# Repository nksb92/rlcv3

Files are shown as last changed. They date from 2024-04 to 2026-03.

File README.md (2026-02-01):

# RLCV3 - RGB LED Controller Version 3

RLCV3 is a comprehensive firmware and hardware project for an embedded LED controller based on the Seeedstudio XIAO ESP32-C3 microcontroller. It is designed to control various LED fixtures including light tubes, panels, and spotlights using DMX512 (wired) and Art-Net (wireless) protocols.

## Features

*   **Multi-Protocol Support**:
    *   **DMX512**: Wired communication via RS485 with termination control.
    *   **Art-Net**: Wireless control over WiFi.
*   **Versatile Hardware Support**: Configurable for different hardware profiles (Addressable Strips, PWM MOSFETs, I2C Panels).
*   **Local User Interface**:
    *   128x32 OLED Display (SSD1306).
    *   Rotary Encoder with Push Button for menu navigation.
*   **Thermal Management**: Integrated PWM fan control with zero-RPM mode support.
*   **Software Architecture**: Hybrid event-driven and polling architecture for responsive UI and high-throughput data processing.

## Hardware Variations

The firmware supports four mutually exclusive hardware profiles defined in `config.h`:

1.  **RGB_IC_TUBE**: For addressable RGB LED strips (e.g., WS2815, WS2811).
2.  **RGB_TUBE**: For non-addressable RGB LED strips controlled via MOSFETs (PWM).
3.  **PANEL**: For configurations involving slave devices controlled via I2C (requires cooling fan).
4.  **SPOT**: For single COB RGB LEDs with MOSFET control and active cooling.

## Getting Started

### Prerequisites

*   **Arduino IDE**: The primary development environment.
*   **ESP32 Board Support**: Install the ESP32 core via Board Manager.

### Dependencies

To ensure stability, the following library versions are recommended (as of Firmware 2.0):

*   **ESP Core**: 3.30.3
*   **Adafruit GFX Library**: 1.12.1
*   **Adafruit NeoPixel**: 1.13.0
*   **Adafruit SSD1306**: 2.5.14
*   **ArtnetWifi**: 1.6.1
*   **EncoderButton**: 1.0.6
*   **FastLED**: 3.9.16
*   **esp_dmx**: 4.1.0 (Note: May require specific fixes for ESP32-C3, see Issue #181)

### Configuration

Before compiling, navigate to `RLC_V3/config.h` and select your hardware profile by uncommenting exactly one of the following lines:

```c
#define RGB_IC_TUBE
// #define RGB_TUBE
// #define PANEL
// #define SPOT
```

You can also toggle debug output in the same file:

```c
// #define DEBUGGING_ENABLED
```

## Repository Structure

*   **RLC_V3/**: Main firmware source code.
*   **LaTeX/**: Comprehensive project documentation, including hardware design, theoretical background, and software architecture details.
*   **Scripts/**: Helper scripts (e.g., Python scripts for bitmap generation).

## Documentation

Detailed documentation regarding the hardware design, PCB fabrication, and theoretical background can be found in the `LaTeX` directory.

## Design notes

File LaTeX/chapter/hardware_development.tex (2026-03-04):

\section{Hardware Development}
\label{sec:hardware_development}

\subsection{Common Hardware Packages and Components}

The controller board integrates several key hardware packages to realize its functionality. For the \ac{DMX} interface, standard \ac{RJ45} connectors are utilized for physical connectivity. The electrical interface is managed by an SN75176 differential bus transceiver \ac{IC}, which is a common choice for \ac{RS485} communication. To ensure compatibility between the 5V levels of the transceiver and the 3.3V logic level of the \ac{MCU}, a voltage divider circuit is implemented for the data lines. \\

Power regulation is achieved using a switching buck converter, a type of \ac{DCDC} converter, to efficiently step down the input voltage to a stable 5V for the system components. The central processing unit selected for this design is the Seeedstudio XIAO ESP32-C3 \ac{MCU}, which provides the necessary computational power, memory, and peripheral interfaces, including \ac{WLAN} connectivity. User input is primarily handled by a rotary encoder, allowing for menu navigation and parameter adjustment. Visual feedback for the \ac{HMI} is provided by an \ac{OLED} display with a resolution of 128x32 pixels, which communicates with the \ac{MCU} via the \ac{I2C} protocol.

\subsection{Hardware Variations for Light Tube}
The project includes different hardware iterations for the tube light fixtures, primarily differing in their \ac{LED} control methodology:

\begin{description}[style=nextline]
	\item[Light Tube V2] This version employs \ac{MOSFET}s to drive the \ac{RGB} \ac{LED}s of the entire tube. Control is achieved using \ac{PWM} signals for each color channel (Red, Green, and Blue), allowing the overall color and intensity of the tube to be adjusted as a single unit.
	\item[Light Tube V3] This iteration advances to addressable \ac{LED} segments. It utilizes a serial communication protocol, similar to that used by the WS2811 \ac{IC}, to set the color of individual \ac{LED} segments within the tube. This enables more complex lighting effects and patterns by controlling different parts of the tube independently.
\end{description}

\subsection{Hardware Variation for Panel}
The Light Panel variant incorporates several distinct design features tailored to its specific application and components. Thermal management for the densely packed \ac{LED}s and associated electronics is addressed by an 80mm cooling fan mounted on the rear of the panel. This fan's speed is regulated via a \ac{PWM} signal from the main controller, allowing for dynamic adjustment of airflow based on thermal load, thereby optimizing cooling performance while minimizing acoustic noise. \\

For distributing lighting information, the panel employs a hierarchical control system. The \ac{MCU} communicates lighting commands to five independent section control units using the \ac{I2C} protocol. These section control units are built around an ATtiny402 \ac{MCU}. Each of these dedicated section controllers is then responsible for driving a bank of 75 WS2815 \ac{RGB} \ac{LED} \ac{IC}s. Within each section, all 75 \ac{LED}s display the same color, as dictated by their respective section controller, allowing for five distinct color zones across the panel. \\

A notable characteristic of this panel variant is its power system. It operates on a 12 Volt input voltage, distinguishing it from other devices in the project that use 24 Volts. This 12V supply is particularly suitable as the WS2815 \ac{LED} \ac{IC}s are designed to be directly powered from a 12V source. This simplifies the power distribution to the \ac{LED}s, potentially reducing the need for additional voltage regulation steps for the \ac{LED} drivers themselves, although the section control units and main \ac{MCU} would still require appropriate voltage levels (e.g., 3.3V or 5V) derived from this main 12V input.

\subsection{Hardware Variation for Spotlight}
This spotlight device incorporates several key design elements. Effective thermal management is achieved through the use of a dedicated aluminum heatsink, which is actively cooled by an attached fan; this is crucial for dissipating the heat generated by the high-power light source. For the 12V fan a separate power rail is used. The fan is controlled via a \ac{PWM} signal depending on the intensity of the light output.\\

The electronics are housed on a custom \ac{PCB}, specifically designed to conform to the physical dimensions and layout requirements of the fixture. The primary light source is a multi-color \ac{RGB} \ac{COB} \ac{LED} chip, which provides a dense array of \ac{LED}s for bright and uniform color output. Each color channel (Red, Green, and Blue) of this \ac{COB} chip is individually controlled via \ac{PWM} signals, allowing for precise color mixing and intensity adjustment. To shape and direct the light output, the fixture is equipped with a lens designed to focus the beam to a 60° angle, providing a defined area of illumination.

\subsection{Schematic Design}
The initial phase of the \ac{PCB} design involves the detailed creation of schematics using specialized \ac{EDA} software. For this project, schematics have been developed using Autodesk Fusion 360, which integrated the capabilities of the formerly separate Autodesk Eagle software, alongside KiCad version 8. A long-term decision has been made to transition future design work predominantly to KiCad 8, leveraging its open-source nature and comprehensive feature set. \\

Within these software environments, the process includes the careful selection and placement of correct component footprints, which accurately represent the physical dimensions and pin configurations of the parts to be used. If standard footprints are unavailable or unsuitable, custom ones are created. Following this, all necessary logical electrical connections between the components are meticulously drawn, defining the complete circuit topology and its intended behavior. \\

A crucial aspect of the design workflow is the reliance on prior experimental validation. The schematics are not merely theoretical constructs but are developed based on the outcomes of thorough testing and experimentation conducted on breadboard prototypes. This practical approach ensures that the fundamental functions of the circuit and the interplay of its components are proven to be working correctly in a tangible, albeit less permanent, setup. By verifying the design's efficacy at the breadboard stage, the risk of errors in the final \ac{PCB} is significantly mitigated, thereby increasing the confidence in ordering and fabricating \ac{PCB}s that will function as intended from the outset.

\subsection{PCB Design and Fabrication}
The design and fabrication of the \ac{PCB}s for this project adhere to several critical considerations to ensure functionality, reliability, and seamless integration within the overall mechanical design. The physical dimensions of each \ac{PCB} are meticulously planned to fit within the specific mechanical parameters and size constraints dictated by the intended enclosure or mounting arrangement. \\

Careful attention is given to the layout of conductive pathways, with adequate track widths employed for both power and signal lines. Power traces are dimensioned to handle the expected current loads without significant voltage drop or excessive heat generation, while signal traces are routed to maintain signal integrity and minimize noise coupling. \\

Components are strategically placed on the board in logical groups, taking into account their functional relationships as well as the placement of input and output connectors to facilitate straightforward wiring and interaction. Furthermore, informative labels and markings are included on the \ac{PCB} silkscreen layer to display crucial information, such as component designators, polarity indicators, or operational notes like the on/off position for a termination resistor switch. To ensure robust mechanical assembly, mounting holes are strategically placed to align with the mechanical design of the enclosure or support structure. \\

All custom \ac{PCB}s utilized throughout this project are fabricated by the external manufacturing service, JLCPCB. This approach allows for access to professional-grade \ac{PCB} production. A specific consideration applies to the \ac{LED} panel variant: due to the high density of surface-mount \ac{LED}s, the WS2815 \ac{LED} components for these panels are assembled onto the \ac{PCB}s directly by JLCPCB as part of their component assembly service. This outsourcing of the \ac{LED} placement significantly saves time for the assembly process for this particular component-dense design. Further details regarding the overall component assembly process for all boards are provided in a subsequent chapter \textit{\ref{sec:component_assembly} \nameref{sec:component_assembly}}.

\subsection{Component Selection}
A comprehensive list of all components used in this project, including their manufacturers and part numbers, can be found in the Bill of Materials in Table \ref{tab:bom}.

\subsection{Component Assembly}\label{sec:component_assembly}
The assembly of the \ac{PCB}s involves distinct stages for \ac{SMD} and \ac{THT} components, employing manual and semi-automated techniques to ensure reliable solder joints and functional boards. \\

\begin{description}[style=nextline]
	\item[\ac{SMD}] The \ac{SMD} assembly process commences with the application of solder paste to the pads on the \ac{PCB}. A stencil, precisely aligned with the \ac{PCB} footprint, is used to ensure accurate deposition of the paste. To achieve consistent solder paste distribution and ensure repeatability across multiple boards, a temporary jig or contraption is constructed. This setup, typically involving securing the stencil with tape and using other \ac{PCB}s as shims, guarantees the correct height and alignment for an even application. Following solder paste application, the individual \ac{SMD} components are meticulously placed onto their designated positions on the \ac{PCB} using a pair of tweezers. Once all components are placed, the entire assembly is subjected to a reflow soldering process using a hot plate. The controlled heating profile of the hot plate melts the solder paste, allowing it to flow and form robust electrical and mechanical connections between the components and the \ac{PCB}. After the board has cooled, a cleaning step is performed using \ac{IPA} and a brush to remove any flux residues or solder debris, ensuring optimal electrical performance and a professional finish.
	
	\item[\ac{THT}] Subsequent to the completion of the \ac{SMD} assembly and reflow process, the \ac{THT} components are manually soldered to the \ac{PCB}. This step is generally performed for all \ac{THT} parts with the notable exception of the \ac{MCU}, which is handled with additional precaution. Before the \ac{MCU} is installed, a critical verification step involves testing the output of the onboard 5V buck \ac{DCDC} converter. The voltage is carefully measured using a multimeter to confirm it is within the correct operational tolerance. Only if this voltage measurement is confirmed to be fine is the \ac{MCU} then soldered onto the board. This sequenced approach, prioritizing the verification of power rails before installing sensitive components like the \ac{MCU}, minimizes the risk of damage due to power supply faults.
\end{description}

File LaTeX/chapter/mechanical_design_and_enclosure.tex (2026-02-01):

\section{Mechanical Design and Enclosure}
\label{sec:mechanical_design}

\subsection{Manufacturing Technologies and Materials}
\label{subsec:manufacturing_tech}
The mechanical construction of the RLCV3 system relies on a combination of additive manufacturing, standardized metal components, and specialized fastening techniques to achieve a robust and professional assembly.

\subsubsection{Additive Manufacturing (3D Printing)}
The fabrication of custom enclosures, structural brackets, and end caps is performed using \ac{FDM}.
A BambuLab X1C printer, equipped with a textured \ac{PEI} build plate, is utilized to ensure consistent adhesion and a high-quality surface finish.\\ 

Two primary thermoplastic filaments are employed based on the functional requirements of the components:
\begin{itemize}
	\item \textbf{BambuLab PLA-Basic}: This material is used for the majority of the structural parts, including the main PCB enclosures, as well as the housing components for the Spotlight and Panel variants \cite{inet:bambulab_pla}.
	It offers a favorable balance of rigidity and dimensional accuracy.
	\item \textbf{BambuLab PLA-CF}: A Carbon Fiber reinforced \ac{PLA} composite is utilized for the tube light end caps \cite{inet:bambulab_placf}.
	The addition of carbon fiber enhances the stiffness of the parts and provides a distinctive matte surface finish, contributing to the aesthetic quality of the visible components.
\end{itemize}

To ensure mechanical integrity, specific print parameters are strictly adhered to.
Components are fabricated using a 0.4 mm nozzle with a layer height of 0.12 mm, allowing for fine detail resolution.
Structural strength is prioritized through the use of increased wall thickness rather than high infill density.
Parts are typically sliced with 3 to 4 wall perimeters and 2 to 3 top and bottom layers.
The infill density is set between 20\% and 30\%, utilizing 3D-honeycomb or cubic patterns to provide isotropic strength distribution.
Components subjected to higher mechanical stress, such as the connector systems detailed in section \ref{subsec:connection_systems}, are designed with significantly thicker walls to withstand operational loads.

\subsubsection{Fastening Technology}
To ensure durability and serviceability, the assembly avoids the use of direct threading into plastic or loose nuts.
Instead, brass threaded inserts (typically M3) are integrated into the 3D-printed components.
These inserts are installed using a heat-set process, where a soldering iron is used to melt the plastic locally, allowing the knurled insert to sink into the part and bond securely upon cooling.
This method provides medium pull-out resistance and torque capability \cite{inet:cnckitchen_inserts}.
Furthermore, it simplifies the assembly process by eliminating the need for a counter-wrench and allows for repeated disassembly without degrading the fastening interface.

\subsubsection{Aluminum Extrusion Profiles}
The core structure of the light tube variants is formed by an extruded aluminum U-profile \cite{inet:alu_profile_amazon}.
This profile serves a dual purpose: it acts as the rigid chassis for the fixture and functions as a passive heatsink for the LED strips \cite{inet:alu6063_properties}.
The selected profile features a width of approximately 27 mm and a height of 12 mm.
Originally supplied in 2-meter lengths, the profiles are cut to 1 meter.
Light diffusion is achieved via a compatible milky-white diffuser cover, which snaps into the profile and adds 13 mm to the total height.
Although specific manufacturer data regarding the thermal resistance and structural modulus of this profile is unavailable, empirical testing has confirmed its suitability for dissipating the thermal load generated by the LEDs in this application.
The precise dimensions provided by the manufacturer, as well as the profile cross-section, can be seen in figure \ref{fig:aluprofileedgy}.

\begin{figure}[H]
	\centering
	
	\caption{Cross-section of the aluminum U-profile used for the tube light structure.}
	\label{fig:aluprofileedgy}
\end{figure}

\subsection{Light Tube Enclosures}
\label{subsec:light_tube_enclosures}
	Holes are drilled through the aluminum profile, and screws are inserted from the inside channel (the surface to which the \ac{LED} strip is adhered).
	These screws engage with the threaded inserts installed in the 3D-printed parts.
	This approach ensures a clean exterior finish with no visible screw heads on the printed parts and provides a secure mechanical connection.
	Typically, each major component is secured with four screws to prevent rotation and ensure structural rigidity.

\subsubsection{Variant V2 (MOSFET)}
\label{subsubsec:light_tube_v2}
In the V2 iteration, the mechanical design integrated the controller housing directly into one of the end caps.
This single-piece assembly served as both the termination for the tube and the enclosure for the \ac{PCB}.
Mechanical mounting for the fixture was provided via a standard tripod screw thread embedded in the housing.
However, this design lacked the modularity required for more advanced mounting scenarios.
Consequently, this mechanical configuration is considered deprecated.
The V2 electronic hardware is compatible with the improved V3 mechanical design, and therefore, no further development is being conducted on the specific V2 enclosure geometry.

\subsubsection{Variant V3 (Addressable)}
\label{subsubsec:light_tube_v3}
The V3 design represents the current standard for the light tube fixtures, featuring a more modular and robust architecture.
The assembly consists of distinct end caps at both the top and bottom of the tube, which incorporate mechanical interfaces for the connector systems.\\

The controller electronics are housed in a dedicated, two-part enclosure mounted along the length of the profile, rather than at the end.
This enclosure comprises a base plate, which is bolted to the aluminum profile and supports the \ac{PCB}, and a removable lid.
The lid protects the electronics while providing necessary apertures for the \ac{OLED} display, input connectors, and the rotary encoder.\\

Electrical connection between the external controller and the internal \ac{LED} strip is achieved by routing three separate cables through drilled holes into the profile's interior.
To facilitate precise assembly, a 3D-printed drill template is available, allowing the user to accurately mark all 14 required holes: 12 for mechanical fastening of the components and 2 for wire feed-throughs.
Inside the profile, a specialized clip is used to secure the data wire.
This clip is designed to be held in place by the adhesive backing of the \ac{LED} strip itself, ensuring the internal wiring remains unobtrusive and does not cast shadows on the diffuser.\\

\subsection{Panel Enclosure}
\label{subsec:panel_enclosure}
The enclosure for the Panel Light variant is constructed around a central structural component, referred to as the main body.
This part serves as the mounting interface for the electronic subsystems, with the \ac{LED} driver \ac{PCB}s positioned on the front face and the main control unit secured to the rear. \\

Electrical connectivity between the rear-mounted controller and the front-facing \ac{LED} modules is established via four wires (carrying power and \ac{I2C} signals), which are routed through a dedicated feed-through channel within the main body.
The lighting array consists of five distinct segments, each managed by its own driver \ac{PCB} mounted on the front.\\

Thermal management is addressed by a cooling fan located at the rear, which is enclosed by a protective lid.
Similarly, the \ac{LED} driver \ac{PCB}s on the front and the main control \ac{PCB} on the back are shielded by their respective covers to ensure safety and prevent accidental contact.\\ 

For positioning and mounting, the assembly features a U-shaped frame.
This frame allows for tilt adjustment and attachment to a standard tripod, secured using an M8 bolt and a wing nut for tool-free adjustment.
Additionally, the design accommodates a diffuser, which can be mounted in conjunction with the U-frame to soften the light output.

\subsection{Spotlight Enclosure}
\label{subsec:spotlight_enclosure}
The mechanical design of the Spotlight variant is centered around a high-performance aluminum heatsink equipped with an active cooling fan, essential for dissipating the heat generated by the high-power \ac{COB} \ac{LED}.\\

The main enclosure body wraps around this heatsink and forms the front face of the fixture.
It features a central aperture designed to accommodate a $60^{\circ}$ lens, which directs the light output.
Internally, a specialized diffusion cube, printed from transparent \ac{PETG} \cite{inet:bambulab_petg}, is positioned between the \ac{LED} and the lens.
This component is critical for blending the distinct red, green, and blue zones of the \ac{COB} \ac{LED} to ensure a uniform color mixture before the light passes through the lens.\\

The control \ac{PCB} is mounted directly to the main body.
A dedicated lid covers the electronics, providing necessary cutouts for peripheral connections and user interface elements.
Similar to the Panel variant, the Spotlight utilizes a U-shaped mounting frame.
This frame facilitates tilt adjustment and tripod mounting, secured via an M8 bolt and a wing nut, allowing for flexible positioning in various lighting setups.

\subsection{Connection Systems}
\label{subsec:connection_systems}
The system features two distinct connection methods designed to address different use cases, ranging from rapid, temporary mounting to robust, structural assembly.

\subsubsection{System \enquote{click \& hope}}
The \enquote{click \& hope} system is a friction-fit mounting solution designed to engage with the external longitudinal grooves of the aluminum profile.
Due to this specific mechanical interface, it is exclusively compatible with the light tube variants.
The primary advantage of this system is the speed of assembly, allowing for the quick attachment of accessories such as tripod mounts.
These mounts typically integrate a threaded insert to interface with standard photography equipment and feature a rosette coupling to enable discrete rotational adjustment. \\

Despite its convenience, the system relies on the clamping force of the printed parts against the profile grooves.
Consequently, it is less structurally secure than bolted connections.
While a spacing bracket for aligning multiple tubes has been prototyped, the ecosystem for this mounting standard is limited.
Due to the superior reliability of the end-cap-based mounting system, further development of this clip-on mechanism is currently not planned.

\subsubsection{System \enquote{screw it!}}
In contrast to the friction-based approach, the \enquote{screw it!} system offers a robust, mechanical interlocking connection.
This system utilizes the structural hardpoints integrated into the end caps of the V3 light tube variants to facilitate the creation of complex, multi-fixture arrays.\\

A comprehensive suite of modular connector components has been developed to support various geometric configurations, including linear couplers, T-pieces, and cross-connectors.
For free-standing applications, specialized feet are utilized.
These feet consist of 3D-printed shells filled with plaster to provide the necessary ballast.
A key maintenance feature of the feet is the detachable mounting adapter; this design allows for the replacement of the mechanical interface in the event of damage without requiring the disposal of the entire weighted base. \\

Assembly is achieved by inserting screws from the rear of the connector components, which engage with the threaded inserts in the tube end caps.
To ensure a seamless appearance and structural rigidity, a clamping mechanism can be applied from the front.
This clamp actively pulls the connected tubes towards the central connector hub, minimizing gaps and preventing rotation.
Figure \ref{fig:crossconnectorclamp} illustrates this assembly from a side perspective to demonstrate the interconnection of parts; for clarity, the end caps are rendered in green, the cross-connector in blue, and the clamping mechanism in red.
Technical drawings detailing the dimensions and tolerances of this interface are provided in appendix~\ref{sec:cad_models} \nameref{sec:cad_models}.

\begin{figure}[H]
	\centering
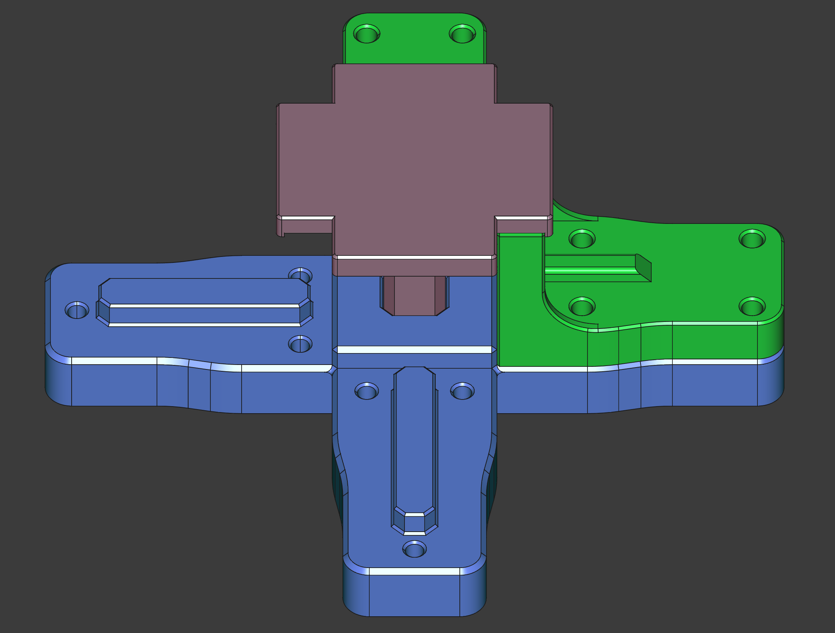
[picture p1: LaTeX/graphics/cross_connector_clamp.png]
	
	\caption{Cross connector with two end caps and clamp mechanism.}
	\label{fig:crossconnectorclamp}
\end{figure}

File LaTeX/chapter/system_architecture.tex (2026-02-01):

\section{System Architecture}
\label{sec:system_architecture}
\subsection{Hardware Core System Block Diagram}
\begin{figure}[H]
	\centering
	
	\caption{Hardware System Architecture}
	\label{fig:hardwarearchitecture}
\end{figure}
The hardware architecture of the developed embedded \ac{LED} controller is segmented into three primary functional blocks: input, processing, and output. This design facilitates modularity and clear separation of concerns within the system. The schematic representation of this architecture can be seen in the provided diagram.

\subsubsection*{Input Block}

The input block is responsible for receiving power, data, and user commands.

\begin{itemize}
	\item \textbf{Power Supply:} The system accepts a flexible \ac{DC} input voltage ranging from 12V to 24V via a dedicated connector. This allows for compatibility with common power supplies found in lighting applications.
	\item \textbf{Programming and Debugging:} A \ac{USB} Type C interface is incorporated for firmware flashing, debugging, and potential serial communication during development.
	\item \textbf{Wired Communication:} An \ac{RS485} interface enables robust, long-distance wired communication, commonly used for protocols like \ac{DMX} in lighting control. A notable feature is an integrated switch to engage or disengage a 120 Ohm termination resistor, crucial for maintaining signal integrity in \ac{RS485} networks.
	\item \textbf{User Interface:} Direct user interaction is managed by a rotary encoder equipped with a push-button function. This allows users to navigate menus displayed on the \ac{HMI} and confirm selections.
	\item \textbf{Wireless Communication:} The controller integrates a 2.4 GHz \ac{WLAN} interface, enabling it to connect to standard wireless networks. This facilitates wireless control primarily through the Artnet protocol, a common standard for transmitting \ac{DMX} data over Ethernet networks.
\end{itemize}

\subsubsection*{Processing Block}

The processing block handles power regulation and executes the core logic of the controller.

\begin{itemize}
	\item \textbf{Power Conversion:} An essential component is the 5V DC-DC converter. This module steps down the incoming 12/24V supply to a regulated 5V. This stable 5V rail powers the sensitive electronic components, including the microcontroller and the display. \\
	For the spotlight a DC-DC converter provides a 12 V power rail. In this case, the input voltage does not match the fan voltage and is therefore needed. 
	\item \textbf{\ac{MCU}:} The central processing unit is the Seeedstudio XIAO ESP32-C3 microcontroller. This \ac{MCU} was chosen for its integrated Wi-Fi capabilities, sufficient processing power for handling communication protocols and control algorithms, and its compact form factor. It executes the firmware that manages inputs, processes control data (e.g., Artnet, \ac{DMX}), and drives the outputs.
\end{itemize}

\subsubsection*{Output Block}

The output block interfaces with the external components that the controller manages.

\begin{itemize}
	\item \textbf{\ac{LED} Control:} The primary function is controlling \ac{LED} hardware. The system is designed to support two main methods: direct serial communication for addressable \ac{LED} strips and \ac{PWM} control for driving different color channels (e.g., \ac{RGB}) of non-addressable \ac{LED}s.
	\item \textbf{Display Interface:} An \ac{I2C} interface is utilized to communicate with the \ac{OLED} display, which serves as the \ac{HMI}. In certain product configurations, such as integrated panel lights, this \ac{I2C} bus may also be used to send control data to other integrated components. An \ac{I2C} level converter is included to shift voltage levels between the 3.3V logic of the \ac{MCU} and the 5V requirement of the other peripherals. The display works with either 3.3V logic or 5V. To only drive the display, the level converter is not needed.
	\item \textbf{Thermal Management:} To ensure reliable operation, the controller incorporates fan control via a standard \ac{PWM} interface, compatible with typical computer fans. This allows the system to regulate its temperature under load.
\end{itemize}

\subsection{Hardware Configuration Options}
While the core architecture remains consistent, different hardware configurations and \ac{PCB}s are available to suit various application requirements:

\begin{itemize}
	\item \textbf{Tube Light V2 (Non-Addressable \ac{LED}s):} This variant utilizes hardware supporting three \ac{PWM} outputs for controlling non-addressable \ac{LED} strips. It omits the fan control output as it's not typically required for this configuration.
	\item \textbf{Tube Light V3 (Addressable \ac{LED}s):} For tube lights using addressable \ac{LED}s, the hardware provides support for a serial data output. Similar to the non-addressable version, fan control is not included.
	\item \textbf{Panel Light:} This configuration uses the same fundamental hardware as the addressable \ac{LED} tube light (serial output capable). However, the \ac{RGB} data for the panel is specifically transmitted via the \ac{I2C} interface instead of the dedicated serial \ac{LED} output. This version includes the hardware connection for fan control.
	\item \textbf{Spot Light:} The spot light employs an individual \ac{PCB} design tailored to its needs. It features three \ac{PWM} outputs for \ac{LED} control and includes the hardware connection for fan control.
	The size of the \ac{PCB} is designed to fit within the casing. The previous \ac{PCB} would not fit.
\end{itemize}

These variations ensure that each product type has an optimized hardware platform based on the core controller design, omitting unnecessary components or adapting interfaces as needed for the specific application.

\subsection{Software Architecture}
\subsubsection{Overview} 
The software architecture utilizes a hybrid execution approach to balance responsiveness with high-throughput data processing. Asynchronous user inputs and low-frequency tasks, such as display updates or button presses, are handled via an event management system. Conversely, high-frequency tasks requiring immediate execution are managed through continuous polling. Additionally, a software timer module is integrated to inject time-based triggers into the event queue.

\subsubsection{Event Management} 
The system implements an event manager utilizing a \ac{FIFO} buffer to store and sequence system events. These events are retrieved and processed sequentially within the main loop via the \textit{process\_event} function. Event definitions and properties are isolated in specific configuration files, facilitating modular adjustments.
Within sourcecode section \ref{pc:event_manager_config} such a configuration can be seen. 

\begin{listing}[H]
	\begin{minted}[autogobble, linenos=true, numberblanklines=true, frame=leftline, framesep=5pt, numbersep=5pt, style=vs, tabsize=2, xleftmargin=10pt, breaklines, fontsize=\small, baselinestretch=1.0, escapeinside=!!]{c}
		const event_cfg_t event_config[] = { 
			// ID Name Priority Queueable {EVT_NONE, "None", EVT_PRIORITY_LOW, false},
			// Input events
			{EVT_ENCODER_CHANGED, "EncoderChanged", EVT_PRIORITY_HIGH, true},
			{EVT_BUTTON_CLICK, "ButtonClick", EVT_PRIORITY_HIGH, false},
			// System events
			{EVT_SAVE_TO_NVM, "SaveToNvm", EVT_PRIORITY_NORMAL, false},
			{EVT_DISPLAY_WAKE, "WakeUpDisplay", EVT_PRIORITY_NORMAL, false},
		};
	\end{minted}
	\caption{Configuration of the event manager system}
	\label{pc:event_manager_config}
\end{listing}

It is possible for the handling of one event to trigger the posting of subsequent events. This capability must be utilized cautiously to prevent the creation of infinite feedback loops where events recursively trigger one another.

\subsubsection{Software Timer Management} 
Software timers are employed to generate events based on time intervals, operating with a time base of 1 ms. The TimerManager checks all active timers for expiry during every iteration of the main loop. Upon expiry, the manager automatically adds the associated event to the FIFO queue. The system supports two operational modes: 

\begin{itemize} 
	\item \textbf{Periodic:} The timer automatically reloads and restarts after expiry. 
	\item \textbf{One Shot:} The timer is disabled immediately after the expiry event is generated.
\end{itemize}
Similar to the configuration of the event manager, the software timers can be configured through a list. 
Each entry represents one timer configuration. 

\subsubsection{Menu Structure}
User interaction with the device primarily occurs through the rotary encoder and its integrated push button, as depicted in the menu structure diagram figure \ref{fig:menustructure}.
\begin{figure}[H]
	\centering
	
	\caption{Structure of the main menu navigation}
	\label{fig:menustructure}
\end{figure}

In the main menu view, turning the rotary encoder allows the user to cycle horizontally through the available function selections (such as \acs{HSV}, \ac{RGB}, \ac{DMX}, Artnet, and Options). The selection does not jump from the last to the first or from the first to the last entry of the menu. 
At both ends an end mark is displayed as user information. \\

Vertical navigation between the main menu level and the corresponding submenu pages is achieved via a long press on the encoder's button. Performing a long press while a main menu item is selected transitions the software into that item's specific submenu, displaying its parameters or options. Conversely, performing another long press while within a submenu returns the user to the main menu selection screen. This hierarchical navigation, visually represented in the provided diagram, allows access to different functionalities and their settings using simple rotary and press actions.

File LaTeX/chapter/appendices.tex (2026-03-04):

\section{Schematic Diagrams}
\begin{figure}[H]
	\centering
	
	\caption{Circuit Diagram Tube V3}
	\label{fig:circuitdrawing}
\end{figure}
\clearpage

\section{Source Code}
The complete source code for the firmware, along with the hardware design files and 3D models, is hosted on GitHub.
The repository can be accessed via the following link: \\
\url{https://github.com/nksb92/rlcv3}
\clearpage

\section{Bill of Materials (BOM)}
\begin{table}[H]
	\centering
	\resizebox{\textwidth}{!}{%
		\begin{tabular}{|l|l|l|l|l|l|l|l|l|l|}
			\hline
			\textbf{Name on PCB} & \textbf{Package} & \textbf{Value} & \textbf{Name} & \textbf{Vender} & \textbf{Part Nbr.} & \textbf{Link} & \textbf{Price One 2025-04-17} & \textbf{Quantity} & \textbf{Total} \\ \hline \hline
			C1, C2, C4, C6, C8 & C1206 & 100n & Capacitor & Mouser & C1206C104K5RAC7867 & \href{https://www.mouser.de/ProductDetail/80-C1206104K5RAC7867}{\textit{View...}} & 0,11305 & 5 & 0,57 € \\ \hline
			C10, C11 & C0805 & 100n & Capacitor & Mouser & 08055C104KAT2A & \href{https://www.mouser.de/ProductDetail/581-08055C104K}{\textit{View...}} & 0,11305 & 2 & 0,23 € \\ \hline
			C12, (C7) & C0805 & 1u & Capacitor & Mouser & 08055C104KAT2A & \href{https://www.mouser.de/ProductDetail/581-08055C104K}{\textit{View...}} & 0,11305 & 1 & 0,11 € \\ \hline
			C3 & C0805 & 10u & Capacitor & Mouser & C0805C106K8PACTU & \href{https://www.mouser.de/ProductDetail/80-C0805C106K8P}{\textit{View...}} & 0,12495 & 1 & 0,12 € \\ \hline
			C9 & C0805 & 4,7u & Capacitor & Mouser & GRM21BZ7YA475KE15K & \href{https://www.mouser.de/ProductDetail/81-GRM21BZ7YA475KE5K}{\textit{View...}} & 0,3094 & 1 & 0,31 € \\ \hline
			D1 & SM71202HTG &  & RS485 Protection & Mouser & SM712-02HTG & \href{https://www.mouser.de/ProductDetail/Littelfuse/SM712-02HTG?qs=aGgfWYEhH7lQgBVBPCUDkw\%3D\%3D}{\textit{View...}} & 0,64498 & 1 & 0,64 € \\ \hline
			D2, D3 & DO-214AC & SK 14 & Diode & Mouser & SK14 & \href{https://www.mouser.de/ProductDetail/637-SK14}{\textit{View...}} & 0,17017 & 2 & 0,34 € \\ \hline
			EN1 & PEC11L-4220F-S0015 &  & Rotary Encoder & Mouser & PEC11L-4220F-S0015 & \href{https://www.mouser.de/ProductDetail/652-PEC11L4220FS0015}{\textit{View...}} & 2,4514 & 1 & 2,45 € \\ \hline
			H1, H2 & 3,2 mm & M3 & Standoff & Mouser & 971080354 & \href{https://www.mouser.de/ProductDetail/710-971080354}{\textit{View...}} & 0,71281 & 2 & 1,43 € \\ \hline
			IC1 & SN75176BDR & RS485 & RS485 Interface & Mouser & SN75176BDR & \href{https://www.mouser.de/ProductDetail/595-SN75176BDR}{\textit{View...}} & 1,07457 & 1 & 1,07 € \\ \hline
			IC2 & SOP65P490X110-8N &  & I2C level shifter & Mouser & TCA9517ADGKR & \href{https://www.mouser.de/ProductDetail/Texas-Instruments/TCA9517ADGKR?qs=\%252BrH4t\%252BeVZ2M4pVnwXR4oNA\%3D\%3D}{\textit{View...}} & 0,94962 & 0 & 0,00 € \\ \hline
			J1 & PJ-044A & DC-Jack & Connector & Mouser & PJ-044A & \href{https://www.mouser.de/ProductDetail/490-PJ-044A}{\textit{View...}} & 0,6902 & 1 & 0,69 € \\ \hline
			J1, J3 & PJ-044A & RJ45 & Connector & Mouser & SS-90000-013 & \href{https://www.mouser.de/ProductDetail/530-SS-90000-013}{\textit{View...}} & 1,7612 & 2 & 3,52 € \\ \hline
			JP2 & 1X04 & OLED & Connector & Amazon & Pin Header & \href{https://www.amazon.de/dp/B09NJMBBLX?ref\_=ppx\_hzsearch\_conn\_dt\_b\_fed\_asin\_title\_3\&th=1}{\textit{View...}} & 0,1402 & 1 & 0,14 € \\ \hline
			JP2 & 1X04 & OLED & Display & Amazon & OLED Display & \href{https://www.amazon.de/dp/B09J7T5SCL?ref\_=ppx\_hzsearch\_conn\_dt\_b\_fed\_asin\_title\_4}{\textit{View...}} & 2,831666667 & 1 & 2,83 € \\ \hline
			L1 & SRN6045 & 15uH & Inductor 15uH & Mouser & NRS6045T150MMGK & \href{https://www.mouser.de/ProductDetail/963-NRS6045T150MMGK}{\textit{View...}} & 0,29393 & 1 & 0,29 € \\ \hline
			R1, R4, R5, R6, R13 & R1206 & 10k & Resistor & Mouser & CRG1206F10K & \href{https://www.mouser.de/ProductDetail/279-CRG1206F10K}{\textit{View...}} & 0,11305 & 5 & 0,57 € \\ \hline
			R2 & R1206 & 120 & Resistor & Mouser & RT0805FRE13120RL & \href{https://www.mouser.de/ProductDetail/603-RT0805FRE13120RL}{\textit{View...}} & 0,11305 & 1 & 0,11 € \\ \hline
			R3 & R1206 & 20k & Resistor & Mouser & RC1206FR-0720KL & \href{https://www.mouser.de/ProductDetail/603-RC1206FR-0720KL}{\textit{View...}} & 0,11305 & 1 & 0,11 € \\ \hline
			R7 & R1206 & 22,1k & Resistor & Mouser & RMCF0805FT22K1 & \href{https://www.mouser.de/ProductDetail/708-RMCF0805FT22K1}{\textit{View...}} & 0,11305 & 1 & 0,11 € \\ \hline
			R8 & R0805 & 115k & Resistor & Mouser & CR0805-FX-1153ELF & \href{https://www.mouser.de/ProductDetail/652-CR0805FX-1153ELF}{\textit{View...}} & 0,11305 & 1 & 0,11 € \\ \hline
			R9, R10, R11, R12 & R0805 & 4k7 & Resistor & Mouser & RK73H2ATTDD4701F & \href{https://www.mouser.de/ProductDetail/660-RK73H2ATTDD4701F}{\textit{View...}} & 0,12019 & 0 & 0,00 € \\ \hline
			S1 & TL3XYO &  & Switch & Mouser & OS102011MA1QN1 & \href{https://www.mouser.de/ProductDetail/611-OS102011MA1QN1}{\textit{View...}} & 0,62237 & 1 & 0,62 € \\ \hline
			U1 & XIAO-ESP32C3 & XIAO-ESP32C3 & Microcontroller & Mouser & 113991054 & \href{https://www.mouser.de/ProductDetail/713-113991054}{\textit{View...}} & 5,6406 & 1 & 5,64 € \\ \hline
			U2 & SOT23-6 &  & Buck converter & Mouser & LMR54406FDBVR & \href{https://www.mouser.de/ProductDetail/595-LMR54406FDBVR}{\textit{View...}} & 1,09718 & 1 & 1,10 € \\ \hline
			&  &  & LED Profile & Amazon & LED Profile & \href{https://www.amazon.de/dp/B07548TMKN?psc=1\&ref=ppx\_yo2ov\_dt\_b\_product\_details}{\textit{View...}} & 11,95 € & 1 & 11,95 € \\ \hline
			&  &  & PCB & JLCPCB &  &  & 0,54 € & 1 & 0,54 € \\ \hline
			&  &  & LED Strip &BTF-Lighting &FCOB SPI RGB IC WS2811 864 & \href{https://www.btf-lighting.com/en-intl/products/fcob-spi-rgb-ic-ws2811-864leds-12v-24v-cob-lights-ra90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}{\textit{View...}} & 5,038 & 1 & 5,04 € \\ \hline
			&  &  & 3D Druck Filament & Bambu Lab & PLA Basic & \href{https://eu.store.bambulab.com/de/products/pla-basic-filament-de?variant=43923829129435}{\textit{View...}} & 1,65 € & 1 & 1,65 € \\ \hline
			&  &  & Threaded Inserts & Amazon & M3S Gewindeeinsatz & \href{https://www.amazon.de/dp/B09ZHSGHXD?ref\_=ppx\_hzsearch\_conn\_dt\_b\_fed\_asin\_title\_5\&th=1}{\textit{View...}} & 0,0899 & 20 & 1,80 € \\ \hline
			&  &  & Screw & Amazon & M3x10 & \href{https://www.amazon.de/gp/product/B01MY4VXCS/ref=ox\_sc\_act\_title\_2?smid=AQ1IBDB6G2RRD\&psc=1}{\textit{View...}} & 0,1099 & 4 & 0,44 € \\ \hline
			&  &  & Screw & Amazon & M3x8 & \href{https://www.amazon.de/gp/product/B08K8FQWCZ/ref=ox\_sc\_act\_image\_1?smid=A1KGD9U4C0ZGWS\&th=1}{\textit{View...}} & 0,119 & 8 & 0,95 € \\ \hline
			&  &  & Screw & Amazon & M3x6 & \href{https://www.amazon.de/gp/product/B08K8F4FL6/ref=ox\_sc\_act\_image\_3?smid=A1KGD9U4C0ZGWS\&th=1}{\textit{View...}} & 0,1046 & 2 & 0,21 € \\ \hline
		\end{tabular}
	}
	\caption[Bill of Materials]{Bill of Materials (Prices from 17.04.2025)}
	\label{tab:bom}
\end{table}
\clearpage

\section{Connection Interfaces}\label{sec:cad_models}
\begin{figure}[H]
	\centering
	
	\caption{Diagram of the connection interface.}
	\label{fig:connectorinterfacetechdrawing}
\end{figure}

\begin{figure}[H]
	\centering
	
	\caption{Diagram of the clamp interface.}
	\label{fig:clampinterfacetechdrawing}
\end{figure}

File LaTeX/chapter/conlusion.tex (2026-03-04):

\section{Conclusion}
\label{sec:conclusion}
A robust firmware implementation for \ac{RGB} \ac{LED} control was developed, incorporating full \ac{DMX}512 and Art-Net protocol integration. The event-driven and timer-based architecture performs reliably and is structured for straightforward extensibility. On the hardware side, the rotary encoder input, \ac{OLED} display, and RJ45/Ethernet interface all operate as specified. The \ac{DC}-\ac{DC} converter supplying the 5 V rail maintains stable operation without significant thermal dissipation. The 3D-printed enclosure meets mechanical requirements, and the screw-terminal interconnect interface functions as intended. \\

The \ac{RS485} \ac{DMX} driver represents the primary area requiring hardware revision. The snap-fit "click \& hope" mechanical connection system proved insufficient in structural rigidity for permanent installations and should be reserved exclusively for temporary fixture assemblies. The spotlight and tube (v3) fixtures are fully operational; the panel light requires further development as outlined in the future work section.

\subsection{Future Work}
\subsubsection{Hardware}
The \ac{RS485} hardware driver requires a redesign to address instability caused by hot-plugging or removing participants on the bus. The revised driver shall integrate bias resistors and optical isolation to decouple the bus from external circuitry. Replacing the current level-shifting approach with a dedicated 3.3 V \ac{RS485} transceiver IC — such as the SP3485 — would eliminate the need for the existing voltage divider. The power supply architecture should be consolidated to a single 3.3 V rail, removing the dual-rail 5 V/3.3 V configuration. Controller migration to a more capable platform, such as the ESP32-S3 or ESP32-C6, warrants evaluation to determine whether the Art-Net transmission latency is bound by processing throughput. For fan control, an optional 12 V rail should be supplied via a dedicated \ac{DC}-\ac{DC} switching converter rather than an \ac{LDO} regulator to improve power conversion efficiency.

\subsubsection{Panel Light}
The light panel should be redesigned as a single-segment, high-power \ac{RGB} module incorporating an integrated heatsink for adequate thermal management. Aluminum heatsink solutions already qualified for comparable panels — such as those used with the Samsung QB288 LM281B — should be considered for adoption. \ac{LED} drive control should be migrated from the current \ac{I2C} slave topology to direct \ac{PWM}-based MOSFET switching, reducing complexity and improving dynamic response. Thermal feedback via dedicated temperature sensors should govern fan speed, replacing the current open-loop, value-driven approach. The control \ac{PCB} rework must also resolve existing \ac{DMX}512 compliance issues.

\subsubsection{Software}
The firmware options menu should expose a function to reset \ac{EEPROM} to factory defaults. A configurable parameter shall allow the user to enable or disable a dedicated dimmer channel for the full tube, including selection of its position within the data frame — either the first or last byte. Color control should be extended to support gradient generation in \ac{HSV} or \ac{RGB} mode, with per-segment individual color assignment and optional interpolation between adjacent segments. Basic generative animations — including rainbow, fire, and candle effects — may be considered for inclusion. The Art-Net implementation requires rework to support more than two universes of data, increasing the addressable segment count for longer \ac{LED} strips. Latency profiling should be conducted to determine whether the issue originates in software or reflects a hardware throughput limitation.

\subsubsection{Hardware Bridge}
A dedicated hardware bridge should be developed, capable of accepting up to four \ac{DMX} input channels and converting to Art-Net output. The device shall incorporate an onboard effects engine supporting configurable fixture profiles for standalone operation. In standalone mode, the output shall be selectable between Art-Net and \ac{DMX}512. The controller platform should be re-evaluated in favor of the STM32 family to meet the processing and peripheral requirements of the bridge functionality.

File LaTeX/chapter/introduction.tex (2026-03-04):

\section{Introduction}
\label{sec:introduction}

\subsection{Motivation}
The effective use of lighting is paramount in creating immersive environments for stage performances, film production, and artistic installations.
The rapid advancement of \ac{LED} technology and embedded systems has democratized access to high-quality lighting tools.
However, a gap often remains between rigid, high-cost professional equipment and fragile, feature-limited hobbyist solutions.
The RLCV3 (\ac{RGB} \ac{LED} Controller Version 3) project was initiated to address this specific niche.
It stems from the need for a highly customizable, robust, and modular lighting ecosystem capable of integrating seamlessly into professional workflows via standard protocols, while remaining accessible and adaptable for custom "light sculpture" configurations.
Building upon the lessons learned from previous iterations, specifically the limitations in mechanical modularity and control resolution encountered in Version 2, this project aims to deliver a professional-grade solution suitable for \ac{DIY} fabrication.

\subsection{Problem Statement and Objectives}
The primary challenge addressed by this work is the development of a unified control architecture capable of driving distinct lighting form factors—specifically linear tubes, flat panels, and spotlights—without requiring disparate hardware designs.
Existing solutions often lack the flexibility to switch between wired \ac{DMX} and wireless Art-Net control within a compact form factor.
Furthermore, mechanical integration in custom builds is frequently overlooked, leading to thermal issues or structural instability.

The specific objectives of this project are:
\begin{itemize}
	\item To design a versatile embedded controller based on the ESP32-C3 \ac{MCU} that supports both wired DMX512 and wireless Art-Net communication.
	\item To develop firmware that adapts to multiple hardware profiles (Addressable \ac{RGB} strips, \ac{PWM} \ac{MOSFET} control, and \ac{I2C}-driven panels) through a centralized configuration mechanism.
	\item To engineer a robust mechanical enclosure system utilizing \ac{FDM} 3D printing and aluminum profiles that facilitates modular interconnection (the "Screw it!" system) and ensures effective thermal management.
	\item To implement a responsive local user interface using an \ac{OLED} display and rotary encoder for standalone configuration.
	\item To validate the system's performance in terms of thermal stability, power reliability, and software responsiveness suitable for live environments.
\end{itemize}

\subsection{Structure of the Article}
The remainder of this document is organized as follows:
\begin{itemize}
	\item \textit{Section \ref{sec:theoretical_background} \nameref{sec:theoretical_background}} provides the theoretical underpinnings, covering embedded systems, \ac{LED} technology, and communication protocols.
	\item \textit{Section \ref{sec:system_architecture} \nameref{sec:system_architecture}} presents the high-level hardware and software design, including the block diagrams and menu structures.
	\item \textit{Section \ref{sec:hardware_development} \nameref{sec:hardware_development}} details the electronic circuit design, \ac{PCB} fabrication, and component selection.
	\item \textit{Section \ref{sec:mechanical_design} \nameref{sec:mechanical_design}} describes the mechanical engineering aspects, focusing on the enclosure design, 3D printing materials, and the modular connection system.
	\item \textit{Section \ref{sec:software_development} \nameref{sec:software_development}} discusses the firmware implementation, including the event-driven architecture, library management, and user interface logic.
	\item \textit{Section \ref{sec:device_assebly} \nameref{sec:device_assebly}} outlines the practical steps for assembling the devices and flashing the firmware.
	\item Finally, \textit{Section \ref{sec:results} \nameref{sec:results}} analyzes the performance of the developed hardware and software, evaluating thermal behavior and overall system functionality.
\end{itemize}

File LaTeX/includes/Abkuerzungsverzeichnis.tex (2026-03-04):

%%%%%%%%%%%%%%%%%%%%%%%%%%%%%%%%%%%%%%%%%%
%%%%%%%% INDEX OF ABBREVITATIONS %%%%%%%%%
%%%%%%%%%%%%%%%%%%%%%%%%%%%%%%%%%%%%%%%%%%
\phantomsection
\addcontentsline{toc}{section}{List of Abbreviations}

\section*{List of Abbreviations}
\begin{multicols}{2}
	\begin{acronym}[1234567890]\itemsep1pt
		\acro{3D}[3D]{Three-Dimensional}
		\acro{API}[API]{Application Programming Interface}
		\acro{AWG}[AWG]{American Wire Gauge}
		\acro{CAD}[CAD]{Computer-Aided Design}
		\acro{COB}[COB]{Chip-on-Board}
		\acro{DC}[DC]{Direct Current}
		\acro{DCDC}[DC-DC]{Direct Current to Direct Current}
		\acro{DIY}[DIY]{Do It Yourself}
		\acro{DMX}[DMX]{Digital Multiplexing}
		\acro{EDA}[EDA]{Electronic Design Automation}
		\acro{EEPROM}[EEPROM]{Electrically Erasable Programmable Read-Only Memory}
		\acro{FDM}[FDM]{Fused Deposition Modeling}
		\acro{FIFO}[FIFO]{First In First Out}
		\acro{GUI}[GUI]{Graphical User Interface}
		\acro{HMI}[HMI]{Human-Machine Interface}
		\acro{HSV}[HSV]{Hue, Saturation, Value}
		\acro{I2C}[I2C]{Inter-Integrated Circuit}
		\acro{IC}[IC]{Integrated Circuit}
		\acro{IDE}[IDE]{Integrated Development Environment}
		\acro{IO}[I/O]{Input/Output}
		\acro{IP}[IP]{Internet Protocol}
		\acro{IPA}[IPA]{Isopropyl Alcohol}
		\acro{LED}[LED]{Light-Emitting Diode}
		\acro{LDO}[LDO]{Low-Dropout Regulator}
		\acro{MCU}[MCU]{Microcontroller Unit}
		\acro{MOSFET}[MOSFET]{Metal-Oxide-Semiconductor Field-Effect Transistor}
		\acro{OLED}[OLED]{Organic Light-Emitting Diode}
		\acro{PCB}[PCB]{Printed Circuit Board}
		\acro{PEI}[PEI]{Polyetherimide}
		\acro{PETG}[PETG]{Polyethylene Terephthalate Glycol}
		\acro{PLA}[PLA]{Polylactic Acid}
		\acro{PNG}[PNG]{Portable Network Graphics}
		\acro{PWM}[PWM]{Pulse Width Modulation}
		\acro{RGB}[RGB]{Red Green Blue}
		\acro{RJ45}[RJ45]{Registered Jack 45}
		\acro{RPM}[RPM]{Revolutions Per Minute}
		\acro{RS485}[RS485]{Recommended Standard 485}
		\acro{SMD}[SMD]{Surface-Mount Device}
		\acro{THT}[THT]{Through-Hole Technology}
		\acro{URL}[URL]{Uniform Resource Locator}
		\acro{USB}[USB]{Universal Serial Bus}
		\acro{VCS}[VCS]{Version Control System}
		\acro{WLAN}[WLAN]{Wireless Local Area Network}
	\end{acronym}
\end{multicols}

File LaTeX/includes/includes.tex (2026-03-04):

%%%%%%%%%%%%%%%%%%%%%%%%%%%%
%%% DOCUMENT
%%%%%%%%%%%%%%%%%%%%%%%%%%%%

\documentclass[12pt,a4paper,captions=tableheading]{article}
% you may add/remove "twoside" above
% or "12pt"

\pdfminorversion=7
\setlength{\headheight}{14.5pt}

%%%%%%%%%%%%%%%%%%%%%%%%%%%%
%%% TIMES-LIKE FONT
%%%%%%%%%%%%%%%%%%%%%%%%%%%%
\usepackage{mathptmx}

%%%%%%%%%%%%%%%%%%%%%%%%%%%%
%%% FONTS ETC.
%%%%%%%%%%%%%%%%%%%%%%%%%%%%

\usepackage[skip=15pt]{caption}
\usepackage[utf8]{inputenc}
\usepackage[T1]{fontenc}
\usepackage[english]{babel}
\usepackage{amsmath}
\usepackage{amsfonts}
\usepackage{amssymb}

%%%%%%%%%%%%%%%%%%%%%%%%%%%%
%%% CODE HIGHLIGHTING
%%%%%%%%%%%%%%%%%%%%%%%%%%%%
\usepackage{fancyvrb}  
\usepackage{minted} 
\usepackage{helvet}

\usepackage{xcolor}
\definecolor{border}{HTML}{ff5500}

\usepackage{tcolorbox}
\usepackage{etoolbox}
% for angular corners, Argument: arc is angular
\BeforeBeginEnvironment{minted}{\begin{tcolorbox}[colback=white, colframe=border, boxrule=0.4mm, arc=15px]}
\AfterEndEnvironment{minted}{\end{tcolorbox}}
\newenvironment{longlisting}{\captionsetup{type=listing}}{}
%\setminted{style=abap}
\setminted{style=arduino}
\usepackage{fancyhdr}
%%%%%%%%%%%%%%%%%%%%%%%%%%%
%%% MISC USEPACKAGES
%%%%%%%%%%%%%%%%%%%%%%%%%%%% 
% font to Times
%\fontfamily{ptm}\selectfont
% font Arial

%\renewcommand{\familydefault}{\sfdefault}
% for figures
\counterwithin{figure}{section}
\usepackage{graphicx}
\graphicspath{ {./graphics/} }
% for the Distances
\usepackage[left=1.50cm, right=1.50cm, top=3.00cm, bottom=2.00cm]{geometry}
% für comment section
\usepackage{verbatim}
% für Zeilenabstand 1,5
\usepackage[onehalfspacing]{setspace}
% for spacing \hlines, default was 3pt,
% but led to a weird overall layout
\usepackage{tabularx}
% for long tables
\usepackage{longtable}
% to use the title and author
%\usepackage{titling}
% the options avoid boxes around the links
\usepackage[colorlinks=false, pdfborder={0 0 0}]{hyperref}
% for bibliography
\usepackage[numbers,square,sort]{natbib}
\bibliographystyle{unsrt}
% for subfigures
\usepackage[caption = false]{subfig}
%\usepackage{subcaption}
%for graphic/ table positioning
\usepackage{float}
%Hurenkind und Schusterjunge unterbinden
\usepackage[subfigure]{tocloft}
\clubpenalty=10000
\widowpenalty=10000
%for no shifting at the beginning of paragraph
\parindent 0pt
%for section in equation number
\numberwithin{equation}{section}
% rotating tables
\usepackage{rotating}
% degree
\usepackage{textcomp}
%line overflow handling
\setlength{\emergencystretch}{10em}
% multirow tables
\usepackage{multirow}
% si units
\usepackage[per-mode = fraction, exponent-product = \cdot, locale = DE]{siunitx}
% variable space
\usepackage{xspace}
%for graphic/ table positioning
\usepackage{float}
%für das Einbinden von Tabellen
\usepackage{booktabs}
%quotation
\usepackage{csquotes}
%abkürzungsverzeichnis
\usepackage[printonlyused]{acronym}
\usepackage{booktabs}
\usepackage{enumitem}
\usepackage{multicol}

\renewcommand{\labelenumii}{\arabic{enumi}.\arabic{enumii}}

%%%%%%%%%%%%%%%%%%%%%%%%%%%%
%%% FORMAT
%%%%%%%%%%%%%%%%%%%%%%%%%%%%

\renewcommand{\cftfigpresnum}{Figure }
\renewcommand{\cfttabpresnum}{Table }
\renewcommand{\listoflistingscaption}{Sourcecode}
\renewcommand{\listingscaption}{Sourcecode}
\renewcommand{\cftfigaftersnum}{:}
\renewcommand{\cfttabaftersnum}{:}

\setlength{\cftfignumwidth}{2.7cm}
\setlength{\cfttabnumwidth}{2.7cm}
\linespread{1.25}
\setlength{\cftfigindent}{0cm}
\setlength{\cfttabindent}{0cm}

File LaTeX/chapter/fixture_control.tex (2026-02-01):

\section{Fixture Control}
\subsection{Daslight 5}

\subsection{ESP32 Artnet}

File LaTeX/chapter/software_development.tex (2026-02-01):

\section{Software Development}
\label{sec:software_development}
\subsection{Development Environment and Tools}
The primary \ac{IDE} employed for the development of the firmware is the Arduino \ac{IDE} \cite{inet:arduino_ide}.
This choice provides a user-friendly \ac{GUI} and a simplified framework for programming embedded systems, managing the underlying complexities of the build process, including the compiler toolchain (e.g., xtensa-esp32-elf-gcc for ESP32-based targets).
Development is conducted using the C++ programming language, tailored with Arduino-specific functions and structures.
The Arduino \ac{IDE} facilitates the installation of necessary board support packages, such as the ESP32 core, through its integrated Board Manager, enabling compilation and code deployment for the target \ac{MCU}.
The specific microcontroller board used in this project is the Seeed Studio XIAO ESP32-C3 \cite{inet:seeed_xiao_esp32c3}.
This board is based on the ESP32-C3 chip, which features a 32-bit RISC-V single-core processor and supports the necessary Wi-Fi connectivity for Art-Net communication. \\

A significant aspect of development within the Arduino ecosystem is the extensive use of libraries.
These include standard Arduino libraries, as well as third-party libraries for specific components like the Adafruit SSD1306 library \cite{inet:ssd1306} for the \ac{OLED} display, and custom-written code modules.
Physical connection to the development boards for programming and data communication is established via a \ac{USB} Type-C interface.
This connection is also utilized for debugging purposes, primarily through the Serial Monitor feature integrated into the Arduino \ac{IDE}, which allows for real-time output of logging messages and variable states from the firmware. \\

To manage code revisions, track changes, and facilitate collaboration, Git is utilized as the \ac{VCS}.
The code repository is hosted on GitHub, allowing for distributed development workflows and maintaining a comprehensive history of the firmware's evolution.

\subsection{Hardware Configuration Management in Software}

The \texttt{config.h} file serves as a centralized compile-time configuration header for the RLCV3 firmware, identified by the \texttt{RLCV3\_FIRMWARE\_VERSION} macro, currently set to "2.0".
Its primary purpose is to adapt the firmware to various hardware targets by defining a specific set of parameters based on a single selected hardware profile.
This is achieved extensively through C preprocessor directives. \\

An important functionality is to toggle debugging information via the serial port.
The option \texttt{DEBUGGING\_ENABLED} toggles between sending information or not.
Different macro definitions are implemented to wrap around the serial print functions.
With this approach, it is not necessary to use a \texttt{\#ifdef} pragma before every serial print call.
The defines for this macro can be seen in source code section \ref{pc:debugging_enabled}.\\
\begin{listing}[H]
	\begin{minted}[autogobble, linenos=true, numberblanklines=true, frame=leftline, framesep=5pt, numbersep=5pt, style=vs, tabsize=2, xleftmargin=10pt, breaklines, fontsize=\small, baselinestretch=1.0, escapeinside=!!]{c}
		// #define DEBUGGING_ENABLED
		#ifdef DEBUGGING_ENABLED
		#define DEBUG_PRINT(...) Serial.print(__VA_ARGS__)
		#define DEBUG_PRINTLN(...) Serial.println(__VA_ARGS__)
		#define DEBUG_PRINTF(...) Serial.printf(__VA_ARGS__)
		#else
		// If disabled, these macros are replaced with nothing
		#define DEBUG_PRINT(...)
		#define DEBUG_PRINTLN(...)
		#define DEBUG_PRINTF(...)
		#endif
	\end{minted}
	\caption{Macro defines for toggling debugging}
	\label{pc:debugging_enabled}
\end{listing}

A core feature is the selection of one out of four mutually exclusive hardware profiles:
\begin{enumerate}
	\item \texttt{RGB\_IC\_TUBE}: For hardware using addressable \ac{RGB} \ac{LED} strips like WS2815 or WS2811.
	\item \texttt{RGB\_TUBE}: For hardware using non-addressable \ac{RGB} \ac{LED} strips controlled by \ac{MOSFET}s via \ac{PWM}.
	\item \texttt{PANEL}: For hardware configurations involving slave devices controlled via \ac{I2C} and requiring a cooling fan.
	\item \texttt{SPOT}: For hardware utilizing a single \ac{COB} \ac{RGB} \ac{LED} with \ac{MOSFET} control and a cooling fan.
\end{enumerate}
A preprocessor check ensures that exactly one of these hardware profiles is uncommented and thus active; otherwise, a compilation error is triggered.\\

Based on the selected hardware profile, a subsequent section defines specific operational parameters.
These parameters include:
\begin{itemize}
	\item \texttt{LED\_OUT\_TYPE}: Specifies the \ac{LED} output control method.
	Possible values are \texttt{LED\_OUT\_RGBIC} for addressable \ac{LED}s, \texttt{LED\_OUT\_MOSFET} for \ac{PWM}-driven \ac{MOSFET} control, or \texttt{LED\_OUT\_I2C} for sending \ac{RGB} and dimmer values to slave devices.
	\item \texttt{NUM\_PIXEL}: Defines the number of individually controllable pixels or segments.
	For non-addressable strips (\texttt{RGB\_TUBE}, \texttt{SPOT}), this is set to 1.
	For addressable strips or panel segments, it is set according to the hardware (e.g., 24 for \texttt{RGB\_IC\_TUBE}, 5 for \texttt{PANEL}).
	The file mandates this value to be between 1 and 170, inclusive.
	\item Pin Definitions: For \texttt{LED\_OUT\_MOSFET} configurations, specific \ac{MCU} pins for Red, Green, and Blue channels (e.g., \texttt{RED\_PIN}, \texttt{GREEN\_PIN}, \texttt{BLUE\_PIN}) are defined.
	\item Fan Control: If a hardware profile requires a fan (indicated by \texttt{FAN\_USAGE}), parameters such as the \ac{PWM} control pin (\texttt{PWM\_PIN}), maximum speed (\texttt{FAN\_MAX\_SPEED}), minimum speed (\texttt{FAN\_MIN\_SPEED}), and zero \ac{RPM} behavior (\texttt{FAN\_ZERO\_RPM}) are defined.
	\texttt{FAN\_ZERO\_RPM} being \texttt{true} allows the fan to turn off below minimum speed, while \texttt{false} clamps it to the minimum speed.
	If \texttt{NO\_FAN} is defined (as in \texttt{RGB\_IC\_TUBE} and \texttt{RGB\_TUBE}), default non-operational fan parameters are set.
\end{itemize}

For instance, if \texttt{SPOT} is selected, \texttt{LED\_OUT\_MOSFET} is defined, along with specific pins for \ac{RGB} control (\texttt{D10}, \texttt{D8}, \texttt{D9}), fan usage is enabled with its control pin set to \texttt{D3}, a speed range from 75 to 255, and \texttt{FAN\_ZERO\_RPM} set to \texttt{true}.
\texttt{NUM\_PIXEL} is set to 1.

The file also incorporates several compile-time checks to validate the configuration:
\begin{itemize}
	\item Verification that \texttt{NUM\_PIXEL} is defined and within the range of 1 to 170.
	\item If \texttt{FAN\_USAGE} is defined, it checks that \texttt{PWM\_PIN}, \texttt{FAN\_MAX\_SPEED}, \texttt{FAN\_MIN\_SPEED}, and \texttt{FAN\_ZERO\_RPM} are all defined.
	\item If \texttt{LED\_OUT\_MOSFET} is defined, it ensures that \texttt{RED\_PIN}, \texttt{GREEN\_PIN}, and \texttt{BLUE\_PIN} are defined.
\end{itemize}
These checks help prevent runtime errors due to incomplete or inconsistent hardware configurations.

In summary, \texttt{config.h} provides a flexible and robust mechanism for managing firmware configurations across different hardware variations from a single codebase, leveraging C preprocessor directives for conditional compilation and validation.

\subsection{Core Application Architecture}
The firmware's logic is driven by a custom-built, cooperative multitasking architecture centered around an event-driven state machine, supplemented by continuous polling for high-frequency tasks.
This hybrid approach ensures both a responsive user interface and efficient handling of real-time data streams like Art-Net.

\subsubsection{Event Handling}
The event system is the backbone of the application and consists of two primary components: the \texttt{event\_manager} and the \texttt{event\_handler}.
\begin{description}[style=nextline]
    \item[\texttt{event\_manager}] This module acts as a centralized \ac{FIFO} queue for all system events.
								   Events can be generated from multiple sources: user interaction (e.g., \texttt{EVT\_ENCODER\_CHANGED} from the rotary encoder), software timers (e.g., \texttt{EVT\_DISPLAY\_SLEEP}), or even from within other event processing routines.
								   The manager ensures that events are stored and processed in the order they are received, with an optional priority system.
    \item[\texttt{event\_handler}] This is the core state machine of the entire application.
								   In the main loop, the \texttt{event\_handler} continuously dequeues events from the \texttt{event\_manager} via its \texttt{process\_event} function.
								   It contains a large switch-case statement that directs program flow based on the current event and the system's state (e.g., the active menu).
								   It is responsible for delegating tasks to the appropriate modules, such as updating the display, saving settings, or changing LED values.
\end{description}

\subsubsection{Menu and State Management}
The user interface's state is managed by a two-tiered state machine system, which provides a clear separation between the main navigation and the detailed settings menu.
\begin{description}[style=nextline]
    \item[\texttt{menu\_structure}] This class manages the top-level navigation state.
									It tracks which main page is currently active (e.g., HSV, RGB, DMX, Art-Net, Settings) and handles the horizontal scrolling between these pages.
									It determines what is shown on the display and how rotary encoder events are interpreted at this top level.
    \item[\texttt{settings\_menu}] When the user enters the "Settings" page, control is handed over to this secondary state machine.
								   The \texttt{settings\_menu} class exclusively manages navigation and value changes within the various sub-options of the settings screen, such as changing the Art-Net universe or DMX address.
								   This specialized handler simplifies the main menu logic.
\end{description}

\subsubsection{Continuous Tasks}
For operations that require constant, high-frequency updates and cannot wait for the event queue, a set of continuous tasks are executed on every iteration of the main \texttt{loop()}.
These tasks, managed in the \texttt{continuous\_tasks.cpp} file, are primarily responsible for handling the incoming stream of Art-Net or DMX data, ensuring that the LED output is updated in real-time without perceptible latency.

\subsection{Software Modules}
The firmware is divided into several distinct modules, each with a specific responsibility.
These modules are largely decoupled and are controlled by the \texttt{event\_handler}, which dispatches events to them.

\begin{description}[style=nextline]
    \item[\texttt{leds}] This module is an abstraction layer for controlling the \ac{LED}s.
	It exposes simple functions to set colors or segments.
	Internally, it handles the specific output protocol based on the hardware configuration in \texttt{config.h} - whether it's driving addressable \ac{LED} strips (like WS2812B), using \ac{PWM} for non-addressable \ac{RGB} \ac{LED}s, or sending data over \ac{I2C}.
    \item[\texttt{dmx}] Manages all DMX512 communication.
	It can act as a DMX receiver to control the LEDs from an external lighting desk.
	The module is responsible for initializing the DMX port and reading the incoming data.
    \item[\texttt{rlc\_artnet}] Implements the Art-Net protocol \cite{inet:artnet_spec}, allowing the device to receive DMX data over a Wi-Fi network.
	It handles the network connection, subscribing to the correct Art-Net universe, and parsing the incoming packets.
    \item[\texttt{nvm}] The Non-Volatile Memory module is responsible for persisting settings across reboots.
	It provides functions to save and load all user-configurable parameters (e.g., HSV values, DMX address, Art-Net settings) to and from the ESP32's flash memory.
    \item[\texttt{fan\_control}] A simple module to manage the speed of the cooling fan via \ac{PWM}, based on the settings defined in \texttt{config.h}.
    \item[\texttt{segments}] This module implements the logic for dividing an \ac{LED} strip into multiple virtual segments.
	It allows the user to control different parts of a single strip as if they were independent fixtures.
    \item[\texttt{c\_hsv} \texttt{and} \texttt{c\_rgb}] These are data-centric classes that manage the state for the HSV and RGB control modes, respectively.
	They hold the current color values and handle the logic for how user inputs modify these values.
\end{description}

\subsection{User Interface Implementation}
\subsubsection{Library for the OLED Display}
For interfacing with and controlling the \ac{OLED} display, the project leverages the well-established Adafruit SSD1306 library \cite{inet:ssd1306}.
This library is a popular choice within the maker and embedded development communities due to its robustness, comprehensive feature set, and broad compatibility, particularly with Arduino-based environments and \ac{MCU}s like the ESP32-C3. \\

The Adafruit SSD1306 library significantly simplifies the development process by abstracting the low-level I2C communication protocol required to interact with the SSD1306 display controller, which is common in monochrome \ac{OLED} modules with resolutions such as 128x32.
It provides a convenient \ac{API} for tasks essential to updating the display, including initializing the screen, clearing the display area, drawing pixels, rendering text in various fonts and sizes, and displaying basic geometric shapes.
By utilizing this library, developers can efficiently implement the necessary visual feedback for the human-machine interface, such as displaying status information, menu options, or parameter values, without needing to delve into the intricate details of the display's command set.
This allows for a quicker and more focused development of the user interface aspects of the embedded system.

\subsubsection{Creating Bitmaps and Aligning Text}
The creation of graphical assets for the \ac{OLED} display, primarily static bitmaps for icons or user interface elements, and the alignment of both these bitmaps and dynamic text are performed through a multi-stage process involving graphic design tools and code integration. \\

The initial design of graphical elements is carried out using Photopea, a web-based image editing tool that serves as an alternative to Adobe Photoshop \cite{inet:photopea}.
Within Photopea, new documents are created with dimensions matching the native resolution of the target \ac{OLED} display (e.g., 128x32 pixels).
Black and white images are then drawn, typically using the pencil tool to create sharp, pixel-perfect shapes suitable for monochrome displays.
Display content is often broken down into logical sections or screens, such as individual main menu items or status icons.
These distinct graphical elements are typically organized on separate layers.
For efficient export, layers intended for conversion can be marked with a specific suffix (e.g., \texttt{-e-}), enabling bulk export as individual \ac{PNG} image files. \\

Once the \ac{PNG} images are prepared, they are converted into C-style byte arrays using the online utility \texttt{image2cpp} \cite{inet:image2cpp}.
Specific settings are applied during this conversion to ensure compatibility with the embedded system and display library: the background color is set to black, with other general settings often left at their default values.
The code output format is selected as \textit{Arduino Code}.
Crucially, the draw mode is configured to \texttt{horizontal - 1 bit per pixel}, which is optimal for monochrome displays where pixel data is packed efficiently.
Additionally, the option to swap bits within a byte is disabled.
The resulting bitmap arrays are then collated and included in a dedicated header file, named \texttt{bitmaps.h}, within the firmware project.
The methods for drawing these bitmaps onto the display are detailed in a subsequent chapter. \\

For dynamic textual information, such as \ac{RGB} values that change during runtime, rendering is handled directly by calling functions from the display \ac{API}.
This allows for text to be updated on-the-fly.
The process of positioning text elements accurately on the display is often iterative.
An initial visual layout is designed in Photopea to get a preliminary feel for placement.
However, final adjustments to coordinates and alignment are typically made within the firmware code, recompiling and testing until the elements fit precisely as intended on the physical screen.
The positions of the bitmaps can be read directly within Photopea.

\subsubsection{Handling Text and Drawing Bitmaps}
Bitmaps are drawn on the display via the \textit{drawBitmap} method.
This method needs 6 inputs.
First, the x- and y-positions as the starting point.
Then the address of the Bitmap itself.
Also, the width and height need to be defined and passed.
Finally, the color of the display needs to be set. \\

To simplify the call of this method, some helper constructs are defined.
First, two enumerations are defined for the index of the width and height as well as the x- and y-coordinates.
The number of items contained in one array for the information also needs to be defined.
A two-dimensional array for the actual x- and y-coordinates and width and height makes it easy to change values if needed.
All helper functions as well as the bitmap defines can be seen in sourcecode section \ref{pc:helper_enums}.
In this example the code for the main menu items is shown.
To keep the example short, only the first three elements are described.
More details can be seen in the actual sourcecode header file \textit{bitmaps.h}.
\begin{listing}[H]
	\begin{minted}[autogobble, linenos=true, numberblanklines=true, frame=leftline, framesep=5pt, numbersep=5pt, style=vs, tabsize=2, xleftmargin=10pt, breaklines, fontsize=\small, baselinestretch=1.0, escapeinside=!!]{c}
		// defintion of the bitmaps
		const unsigned char BITMAP_LEFT_END_MENU[] PROGMEM = { ... }
		const unsigned char BITMAP_ARTNET_REC_MENU[] PROGMEM = { ... }	
		const unsigned char BITMAP_DMX_MENU[] PROGMEM = { ... }
		// enumeration for addressing in array
		enum {
			LEFT_END_MENU,
			ARTNET_REC_MENU,
			DMX_MENU,
		};
		// enumeration for width and height
		enum {
			WIDTH,
			HEIGHT
		};
		// enumeration for x- and y-alignment
		enum {
			x,
			y
		};
		// define number of bitmaps for array
		#define BITMAP_MAIN_MENU_LEN 3
		// real width and height values
		int W_H_MATRIX_MAIN_MENU[BITMAP_MAIN_MENU_LEN][2] = {
			{ 12, 21 }, // Left end menu
			{ 23, 19 }, // artnet_rec menu
			{ 35, 12 }, // DMX menu
		};
		// real x- and y- coordinates
		int X_Y_MATRIX_MAIN_MENU[BITMAP_MAIN_MENU_LEN][2] = {
			{ 58, 2 },	// Left end menu
			{ 53, 3 },	// artnet_rec menu
			{ 47, 6 },	// DMX menu
		};
		// bitmaps as a array 
		const unsigned char *BITMAP_MAIN_MENU_ARRAY[BITMAP_MAIN_MENU_LEN] = {
			BITMAP_LEFT_END_MENU,
			BITMAP_ARTNET_REC_MENU,
			BITMAP_DMX_MENU,
		};
	\end{minted}
\caption{Helper constructs for drawing bitmaps}
\label{pc:helper_enums}
\end{listing}
These defines and enumerations don't do anything on their own.
In order to display a bitmap on the screen, the information needs to be passed to the \textit{drawBitmap} method.

\subsubsection{Main Menu Item Selection}
Within the main menu, there are always three submenu page options shown.
The first and last ones indicate the start and end of the selection.
These items are not selectable, as they are only indicators.
Figure \ref{fig:menuitemselection} shows the abstract build of the menu structure.
\begin{figure}[H]
	\centering
	
	\caption{Arrangement of the Main Menu Items}
	\label{fig:menuitemselection}
\end{figure}
The selection frame always stays in the same place.
If the user switches the currently selected menu item, the displayed items will be replaced.
Also the menu navigation indicator on the bottom switches to the next selection.
More on this topic in chapter \ref{sec:menu_navigation_indicator} \nameref{sec:menu_navigation_indicator}.
Within the figure the indicator shows the selection of the first menu item.
Switching to the second menu item will shift all previously shown menu items by one to the left.
Therefore, the left menu item will be 1, the middle 2, and the right 3. \\

Scrolling over the edge of the menu is not possible.
If the user reaches the end of the menu and continues switching, nothing will happen.
This means, the user can only switch to the previous item in this instance.
The same occurs with the first item, except the direction changes.

\subsubsection{Menu Navigation Indicator}\label{sec:menu_navigation_indicator}

\begin{figure}[H]
	\centering
	
	\caption{Position indicator for Menu navigation}
	\label{fig:menunavigationindicator}
\end{figure}
Counting the used radii and gaps for each number $n$ results in the list below.
From there, a generalized equation can be formulated.
\begin{align*}
	n = 3  \quad 1.5 \text{ gaps}  \quad 3 \cdot r \\
	n = 4  \quad 2.0 \text{ gaps}  \quad 4 \cdot r \\
	n = 5  \quad 2.5 \text{ gaps}  \quad 5 \cdot r 
\end{align*}
With this listing of possible numbers $n$ one can see, the summed distance on one side of the center of the display is always $n \cdot r$.
The distance with the gaps behaves similarly.
Here is the total distance on one side of the center line $\frac{n}{2} \cdot d_{gap}$.
The following equation to calculate the start x-position can thus be generalized with the radius $r$, the distance of the gap $d_{gap}$, the number of circles to be drawn $n$, and the center display position $x_{center} = 128 / 2$.

\begin{align*}
	 x_{start} = x_{center} - \left( \left(n \cdot r\right) + \left(\frac{n}{2} \cdot d_{gap}\right)\right)
\end{align*}
The start position can therefore be calculated.
From there, a for loop generates the empty circles.
If the index of the current menu item selection is reached, the circle is completely filled.
This is done to symbolize the current position in the menu.
The following are some examples with different numbers of circles.
\begin{align*}
	n & = 3 \quad r = 2 \quad d_{gap} = 5\\
	x_{start_3} &= 64 - \left(\left(3 \cdot 2 \right) + \left(\frac{3}{2} \cdot 5 \right) + 0 \right) = 50.5 \approx 50 \\
	n & = 4 \quad r = 2 \quad d_{gap} = 5\\
	x_{start_4} &= 46 \\
	n & = 5 \quad r = 2 \quad d_{gap} = 5\\
	x_{start_5} &= 41,5 \approx 41
\end{align*}
During testing, it was observed that a correction of one pixel shift to the right improves the result.
This was observed with $n=5$ circles.
For different numbers this might not be needed.
With the correction, the equation \ref{eq:final_calc_dots} can be used in the source code.
\begin{align}\label{eq:final_calc_dots}
	x_{start} = x_{center} - \left( \left(n \cdot r\right) + \left(\frac{n}{2} \cdot d_{gap}\right)\right) + 1
\end{align}

\subsection{Library Version Management}
To ensure stability and prevent compatibility issues that could break the firmware's functionality, it is crucial to use specific versions of the external libraries upon which the project depends.
The firmware has been developed and tested with the following library versions, and adherence to these versions is recommended for compilation and deployment:

\begin{multicols*}{2}	
	\begin{description}[style=nextline]
		\item[ESP Core:] Version 3.30.3
		\item[Adafruit GFX Library:] Version 1.12.1 \cite{inet:adafruit_gfx}
		\item[Adafruit NeoPixel:] Version 1.13.0 \cite{inet:adafruit_neopixel}
		\item[Adafruit SSD1306:] Version 2.5.14 \cite{inet:ssd1306}
		\item[ArtnetWifi:] Version 1.6.1 \cite{inet:artnetwifi}
		\item[EncoderButton:] Version 1.0.6 \cite{inet:encoderbutton}
		\item[FastLED:] Version 3.9.16 \cite{inet:fastled}
		\item[esp\_dmx:] Version 4.1.0 \cite{inet:esp_dmx}. It is important to note that this version may require a specific fix as detailed in the following GitHub issue discussion: \url{https://github.com/someweisguy/esp_dmx/issues/181#issuecomment-2619261884}.
	\end{description}
\end{multicols*}

Using versions different from those listed above may lead to unexpected behavior or compilation errors due to changes in library \ac{API}s or internal functionality.
It is advised to manage these library versions carefully within the development environment.

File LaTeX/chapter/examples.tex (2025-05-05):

\section{Assembly and Integration}
\label{sec:assembly_integration_hw}
\begin{itemize}
	\item Describe the process of assembling the electronic components into the designed enclosures for each product variation.
	\item Mention any challenges or specific steps involved in the mechanical integration.
\end{itemize}

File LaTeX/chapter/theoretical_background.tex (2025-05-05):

\section{Theoretical Background}
\label{sec:theoretical_background}
\subsection{Embedded Systems}
An embedded system is fundamentally a computer system designed for a specific, dedicated function within a larger mechanical or electrical system. It comprises a combination of hardware, typically centered around a processor or \ac{MCU}, memory for storing software and data, and peripheral \ac{IO} devices for interacting with the external environment or the larger system it controls. Unlike general-purpose computers, embedded systems are often constrained by factors such as cost, size, power consumption, and real-time performance requirements, and their software, known as firmware, is specifically tailored to their dedicated task. The \ac{LED} controller developed in this work is an example of such an embedded system.

\subsection{RGB LEDs and Control Methods}
\ac{RGB} \ac{LED}s are semiconductor light sources that combine three individual \ac{LED} elements: red, green, and blue within a single package. By varying the intensity of each primary color, a wide spectrum of colors, including white, can be produced through additive color mixing. Controlling these \ac{LED}s typically involves one of two primary methods relevant to this project. The first method uses \ac{PWM} signals applied independently to each color channel of non-addressable \ac{LED}s, allowing for intensity control of the entire strip or fixture as a single unit. The second method employs addressable \ac{LED}s, where each \ac{LED} (or a small group) incorporates an \ac{IC}. These \ac{IC}s allow the \ac{LED}s to be connected in series and controlled individually via a serial data protocol, enabling complex effects and patterns across the length of an \ac{LED} strip or within a fixture. The choice of control method depends on the specific application requirements, balancing factors like cost, complexity, and the desired level of control granularity.

\subsection{Communication Protocols}
The embedded \ac{LED} controller supports industry-standard communication protocols for receiving lighting control data, enabling integration into various professional and hobbyist setups. Wired communication is primarily handled via the \ac{DMX} protocol, technically known as DMX512. \ac{DMX} is a unidirectional, serial digital protocol transmitted over an \ac{RS485} physical layer, designed for controlling stage lighting and effects. It allows for the addressing and control of up to 512 individual channels within a single "universe," typically corresponding to parameters like intensity or color values for different fixtures. The controller implements \ac{DMX} reception capabilities, allowing it to act as a DMX-controllable device.\\

For network-based control, particularly over wireless networks, the controller utilizes the Art-Net protocol. Art-Net is designed to transmit \ac{DMX} data packets over \ac{IP} networks, leveraging standard networking infrastructure like Ethernet or \ac{WLAN}. This allows for significantly larger systems spanning multiple \ac{DMX} universes and facilitates control from software or consoles connected to the same network. The controller's integrated \ac{WLAN} interface enables it to receive Art-Net commands wirelessly, translating them into the appropriate \ac{LED} output signals. The support for both \ac{DMX} and Art-Net provides flexibility in how the controller is integrated and controlled within a lighting system.

\subsection{User Interface Components}
The primary components facilitating user interaction with the embedded \ac{LED} controller constitute the device's \ac{HMI}. These components allow the user to configure settings, select operating modes, and view status information directly on the device.\\

The main input mechanism is a rotary encoder combined with an integrated push button. This single component serves multiple roles: rotation is used for navigating through menu options or adjusting parameter values, a short press typically confirms a selection or cycles through options within a submenu, and a long press is used to switch between the main menu and submenu levels. This provides a compact and intuitive method for controlling the device's functions without requiring numerous buttons. \\

Visual feedback is provided by a monochrome \ac{OLED} display. This display renders the menu structure, shows current parameter values (such as \ac{HSV} or \ac{RGB} levels, \ac{DMX} addresses, or Art-Net settings), and indicates system status, potentially including connectivity icons or confirmation messages like "Saved". The combination of the rotary encoder input and the \ac{OLED} display output forms the complete local user interface for the controller.

\subsection{Power Supply}
The embedded controller is designed to operate from a flexible main power source, accepting a \ac{DC} input voltage ranging from 12 to 24 Volts via a dedicated connector. Internally, an integrated \ac{DCDC} voltage converter steps this input down to a regulated 5 Volts. This stable 5 Volt supply rail powers the core processing components, including the \ac{MCU} and the \ac{OLED} display. Additionally, the \ac{USB} Type C interface, primarily intended for programming and debugging, can also supply power to the board, typically at 5 Volts, although the main operational power is expected from the 12-24 Volt input.

\subsection{Additive Manufacturing (3D Printing)}\label{subsec:theoretical_3d_printing}
Additive manufacturing, commonly known as \ac{3D} printing, encompasses a set of processes used to create \ac{3D} objects by adding material layer by layer. This approach contrasts fundamentally with traditional subtractive manufacturing methods, which involve removing material from a larger block (e.g., milling or turning). \ac{3D} printing typically starts with a digital model, often created using \ac{CAD} software, which is then sliced into thin cross-sections. The printer deposits, fuses, or solidifies material (such as plastics, resins, metals, or composites) according to these cross-sections, gradually building up the final object. This technology is particularly advantageous for rapid prototyping, creating complex geometries, producing customized parts, and enabling low-volume production runs, such as potentially fabricating custom enclosures or mounting hardware for embedded systems like the one described in this work.

\subsection{Aluminum Extrusion Profiles}\label{subsec:theoretical_aluminum_profiles}
Aluminum extrusion profiles are commonly utilized in mechanical design and construction due to their advantageous properties, including a high strength-to-weight ratio, corrosion resistance, and excellent thermal conductivity. The extrusion process allows for the creation of complex cross-sectional shapes with integrated features like channels, slots, and mounting points. These features make aluminum profiles highly suitable for creating modular and customizable enclosures and structures. In the context of lighting applications, particularly for linear fixtures like the tube light variants developed in this project, these profiles serve multiple purposes. They provide a robust yet lightweight housing, act as an effective heat sink for dissipating thermal energy generated by the \ac{LED}s and electronics, and often include channels designed to hold the \ac{LED} strips, diffusers, and associated \ac{PCB}s securely in place, contributing to a clean and integrated final design.

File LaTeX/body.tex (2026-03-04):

% Preheader
\include{./includes/includes}
% Document

\begin{document}
	
	% Add title without page numbering or any other format
	\pagenumbering{Roman}
	\pagestyle{empty}
	\include{./includes/deckblatt}

	% Display page numbering
	\pagestyle{plain}

	% Table of contents
	\phantomsection
	\addcontentsline{toc}{section}{Contents}
	\tableofcontents
	\newpage
	
	\renewcommand{\arraystretch}{1.5}
	
	% abbreviations
	\include{./includes/Abkuerzungsverzeichnis}
	\newpage
	
	\renewcommand{\arraystretch}{1.25}
	% list of figures
	\phantomsection
	\addcontentsline{toc}{section}{\listfigurename}
	\listoffigures
	\newpage

	% list of tables
	\phantomsection
	\addcontentsline{toc}{section}{\listtablename}
	\listoftables
	
	\newpage
	
	% list of Programmcode
	\phantomsection
	\addcontentsline{toc}{section}{Source Code}
%	\lstlistoflistings	
	\listoflistings
	\newpage
	
	% Include the abstract
	%\phantomsection
	%\input{./chapter/abstract}
	%\newpage
	
	% nomenklatur
	%\input{./chapter/nomenklatur}
	%\newpage

	% change page and chaper numbering
	\pagenumbering{arabic}
	\setcounter{section}{0}

	%%%%%%%%%%%%%%%%%%%%%%%%%%%%%%%%%%%%%%%%%%%%%%%
	%%%%%%%%%%  MAIN PART
	%%%%%%%%%%%%%%%%%%%%%%%%%%%%%%%%%%%%%%%%%%%%%%%
	\pagestyle{fancy}
	\fancyhf{} % Clear all header and footer fields
	\fancyhead[C]{\nouppercase{\leftmark}} % Place the current section title on the left side of the header
	\fancyfoot[C]{\thepage} % Place the page number on the right side of the footer
	\renewcommand{\headrulewidth}{0pt} % Optional: Remove the line above the header
	\renewcommand{\footrulewidth}{0pt} % Optional: Remove the line above the footer
	% ADD YOUR CHAPTER HERE
	\input{./chapter/introduction}
	\newpage
	\input{./chapter/theoretical_background}
	\newpage
	\input{./chapter/system_architecture}
	\newpage
	\input{./chapter/hardware_development}
	\newpage
	\input{./chapter/mechanical_design_and_enclosure}
	\newpage
	\input{./chapter/software_development}
	\newpage
	\input{./chapter/assembly_and_integration}
	\newpage
	\input{./chapter/results}
	\newpage
	\input{./chapter/conlusion}
	\newpage
	\appendix
	\input{./chapter/appendices}
	\newpage
	
	%\input{./chapter/Problemstellung}
	%\newpage
	
	%%%%%%%%%%%%%%%%%%%%%%%%%%%%%%%%%%%%%%%%%%%%%%%
	%%%%%%%%%%  Literature and Appendix
	%%%%%%%%%%%%%%%%%%%%%%%%%%%%%%%%%%%%%%%%%%%%%%%
%	\fancyhf{} % Clear all header and footer fields
	% switch page numberin to roman
	\pagenumbering{Roman}

	% set counter for page numbering.
	% !!!!!!!!!!!!!!!!!!!!!!!!!!!!!!!!!!!!!!!!!!!!!!
	% !!!!!!!!!!!!!!!!!!!!!!!!!!!!!!!!!!!!!!!!!!!!!!
	% Has to be done manually !!!!!!!!!!!!!!!!!!!!!!
	\setcounter{page}{9}

	% Literature
	\phantomsection
	\addcontentsline{toc}{section}{References}
	\bibliography{./includes/literatur}
	\newpage

	% Appendix
	%\appendix

	% Pack den Anhang hier rein
	%\include{./chapter/Anhang}

\end{document}

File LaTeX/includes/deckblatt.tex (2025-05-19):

%% Deckblatt
%\thispagestyle{TitelSeite}
\thispagestyle{empty}
\begin{verbatim}

\end{verbatim}

\begin{center}
\large{Development Notes }

\end{center}

\begin{verbatim}

\end{verbatim}
\begin{center}
	\makebox[\linewidth]{\rule{\linewidth}{0.4pt}}
\end{center}
\begin{verbatim}
	
\end{verbatim}
\begin{center}
	\textbf{\huge RLCV3} 
\end{center}
\begin{verbatim}
	
\end{verbatim}

\begin{center}
	\large Design and Development of an Embedded System Utilizing Dedicated Hard- and Software Subsystems for RGB LED Fixture Control
\end{center}
\begin{verbatim}
	
\end{verbatim}
\begin{center}
	\makebox[\linewidth]{\rule{\linewidth}{0.4pt}}
\end{center}

\begin{verbatim}

\end{verbatim}

\begin{center}
	by Niko Kassubek
\end{center}
%% Ende des Deckblatts

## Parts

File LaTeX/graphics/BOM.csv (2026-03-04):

Name on PCB | Package | Value | Name | Vender | Part Nbr. | Link | Price One 2025-04-17 | Quantity | Total | n | Quantity n | Price for | Available | Need to buy
C1, C2, C4, C6, C8 | C1206 | 100n | Capacitor | Mouser | C1206C104K5RAC7867 | https://www.mouser.de/ProductDetail/80-C1206104K5RAC7867 | 0,11305 | 5 | 0,57 € | 26 | 130 | 14,70 € |  | 130
C10, C11 | C0805 | 100n | Capacitor | Mouser | 08055C104KAT2A | https://www.mouser.de/ProductDetail/581-08055C104K | 0,11305 | 2 | 0,23 € | 26 | 52 | 5,88 € |  | 52
C12, (C7) | C0805 | 1u | Capacitor | Mouser | 08055C104KAT2A | https://www.mouser.de/ProductDetail/581-08055C104K | 0,11305 | 1 | 0,11 € | 26 | 26 | 2,94 € |  | 26
C3 | C0805 | 10u | Capacitor | Mouser | C0805C106K8PACTU | https://www.mouser.de/ProductDetail/80-C0805C106K8P | 0,12495 | 1 | 0,12 € | 26 | 26 | 3,25 € |  | 26
C9 | C0805 | 4,7u | Capacitor | Mouser | GRM21BZ7YA475KE15K | https://www.mouser.de/ProductDetail/81-GRM21BZ7YA475KE5K | 0,3094 | 1 | 0,31 € | 26 | 26 | 8,04 € |  | 26
D1 | SM71202HTG |  | RS485 Protection | Mouser | SM712-02HTG | https://www.mouser.de/ProductDetail/Littelfuse/SM712-02HTG?qs=aGgfWYEhH7lQgBVBPCUDkw%3D%3D | 0,64498 | 1 | 0,64 € | 26 | 26 | 16,77 € |  | 26
D2, D3 | DO-214AC | SK 14 | Diode | Mouser | SK14 | https://www.mouser.de/ProductDetail/637-SK14 | 0,17017 | 2 | 0,34 € | 26 | 52 | 8,85 € |  | 52
EN1 | PEC11L-4220F-S0015 |  | Rotary Encoder | Mouser | PEC11L-4220F-S0015 | https://www.mouser.de/ProductDetail/652-PEC11L4220FS0015 | 2,4514 | 1 | 2,45 € | 26 | 26 | 63,74 € |  | 26
H1, H2 | 3,2 mm | M3 | Spacer | Mouser | 971080354 | https://www.mouser.de/ProductDetail/710-971080354 | 0,71281 | 2 | 1,43 € | 26 | 52 | 37,07 € |  | 52
IC1 | SN75176BDR | RS485 | RS485 Interface | Mouser | SN75176BDR | https://www.mouser.de/ProductDetail/595-SN75176BDR | 1,07457 | 1 | 1,07 € | 26 | 26 | 27,94 € |  | 26
IC2 | SOP65P490X110-8N |  | I2C level shifter | Mouser | TCA9517ADGKR | https://www.mouser.de/ProductDetail/Texas-Instruments/TCA9517ADGKR?qs=%252BrH4t%252BeVZ2M4pVnwXR4oNA%3D%3D | 0,94962 | 0 | 0,00 € | 26 | 0 | 0,00 € |  | 0
J1 | PJ-044A | DC-Jack | Connector | Mouser | PJ-044A | https://www.mouser.de/ProductDetail/490-PJ-044A | 0,6902 | 1 | 0,69 € | 26 | 26 | 17,95 € |  | 26
J1, J3 | PJ-044A | RJ45 | Connector | Mouser | SS-90000-013 | https://www.mouser.de/ProductDetail/530-SS-90000-013 | 1,7612 | 2 | 3,52 € | 26 | 52 | 91,58 € |  | 52
JP2 | 1X04 | OLED | Connector | Amazon | Pin Header | https://www.amazon.de/dp/B09NJMBBLX?ref_=ppx_hzsearch_conn_dt_b_fed_asin_title_3&th=1 | 0,1402 | 1 | 0,14 € | 26 | 26 | 3,65 € |  | 26
JP2 | 1X04 | OLED | Display | Amazon | OLED Display | https://www.amazon.de/dp/B09J7T5SCL?ref_=ppx_hzsearch_conn_dt_b_fed_asin_title_4 | 2,831666667 | 1 | 2,83 € | 26 | 26 | 73,62 € |  | 26
L1 | SRN6045 | 15uH | Inductor 15uH | Mouser | NRS6045T150MMGK | https://www.mouser.de/ProductDetail/963-NRS6045T150MMGK | 0,29393 | 1 | 0,29 € | 26 | 26 | 7,64 € |  | 26
R1, R4, R5, R6, R13 | R1206 | 10k | Resistor | Mouser | CRG1206F10K | https://www.mouser.de/ProductDetail/279-CRG1206F10K | 0,11305 | 5 | 0,57 € | 26 | 130 | 14,70 € |  | 130
R2 | R1206 | 120 | Resistor | Mouser | RT0805FRE13120RL | https://www.mouser.de/ProductDetail/603-RT0805FRE13120RL | 0,11305 | 1 | 0,11 € | 26 | 26 | 2,94 € |  | 26
R3 | R1206 | 20k | Resistor | Mouser | RC1206FR-0720KL | https://www.mouser.de/ProductDetail/603-RC1206FR-0720KL | 0,11305 | 1 | 0,11 € | 26 | 26 | 2,94 € |  | 26
R7 | R1206 | 22,1k | Resistor | Mouser | RMCF0805FT22K1 | https://www.mouser.de/ProductDetail/708-RMCF0805FT22K1 | 0,11305 | 1 | 0,11 € | 26 | 26 | 2,94 € |  | 26
R8 | R0805 | 115k | Resistor | Mouser | CR0805-FX-1153ELF | https://www.mouser.de/ProductDetail/652-CR0805FX-1153ELF | 0,11305 | 1 | 0,11 € | 26 | 26 | 2,94 € |  | 26
R9, R10, R11, R12 | R0805 | 4k7 | Resistor | Mouser | RK73H2ATTDD4701F | https://www.mouser.de/ProductDetail/660-RK73H2ATTDD4701F | 0,12019 | 0 | 0,00 € | 26 | 0 | 0,00 € |  | 0
S1 | TL3XYO |  | Switch | Mouser | OS102011MA1QN1 | https://www.mouser.de/ProductDetail/611-OS102011MA1QN1 | 0,62237 | 1 | 0,62 € | 26 | 26 | 16,18 € |  | 26
U1 | XIAO-ESP32C3 | XIAO-ESP32C3 | Microcontroller | Mouser | 113991054 | https://www.mouser.de/ProductDetail/713-113991054 | 5,6406 | 1 | 5,64 € | 26 | 26 | 146,66 € |  | 26
U2 | SOT23-6 |  | Buck converter | Mouser | LMR54406FDBVR | https://www.mouser.de/ProductDetail/595-LMR54406FDBVR | 1,09718 | 1 | 1,10 € | 26 | 26 | 28,53 € |  | 26
 |  |  | LED Profile | Amazon | LED Profile | https://www.amazon.de/dp/B07548TMKN?psc=1&ref=ppx_yo2ov_dt_b_product_details | 11,95 € | 1 | 11,95 € | 26 | 26 | 310,70 € |  | 26
 |  |  | PCB | JLCPCB |  |  | 0,54 € | 1 | 0,54 € | 26 | 26 | 14,04 € |  | 26
 |  |  | LED Strip | Ali Express | COB LED Strip | https://de.aliexpress.com/item/1005005648644241.html | 5,038 | 1 | 5,04 € | 26 | 26 | 130,99 € |  | 26
 |  |  | 3D Druck Filament | Bambu Lab | PLA Basic | https://eu.store.bambulab.com/de/products/pla-basic-filament-de?variant=43923829129435 | 1,65 € | 1 | 1,65 € | 26 | 26 | 42,82 € |  | 26
 |  |  | Threaded Inserts | Amazon | M3S Gewindeeinsatz | https://www.amazon.de/dp/B09ZHSGHXD?ref_=ppx_hzsearch_conn_dt_b_fed_asin_title_5&th=1 | 0,0899 | 20 | 1,80 € | 26 | 520 | 46,75 € |  | 520
 |  |  | Screw | Amazon | M3x10 | https://www.amazon.de/gp/product/B01MY4VXCS/ref=ox_sc_act_title_2?smid=AQ1IBDB6G2RRD&psc=1 | 0,1099 | 4 | 0,44 € | 26 | 104 | 11,43 € |  | 104
 |  |  | Screw | Amazon | M3x8 | https://www.amazon.de/gp/product/B08K8FQWCZ/ref=ox_sc_act_image_1?smid=A1KGD9U4C0ZGWS&th=1 | 0,119 | 8 | 0,95 € | 26 | 208 | 24,75 € |  | 208
 |  |  | Screw | Amazon | M3x6 | https://www.amazon.de/gp/product/B08K8F4FL6/ref=ox_sc_act_image_3?smid=A1KGD9U4C0ZGWS&th=1 | 0,1046 | 2 | 0,21 € | 26 | 52 | 5,44 € |  | 52

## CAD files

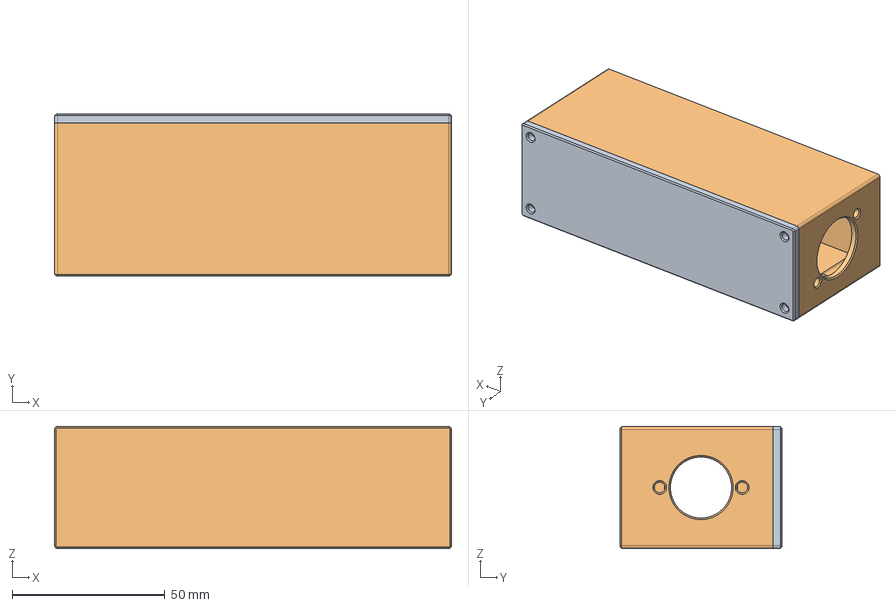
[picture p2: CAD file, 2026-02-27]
3d_models/DMX Adapter/housing_xlr_rj45.stp
130.0 x 53.0 x 40.0 mm
lid

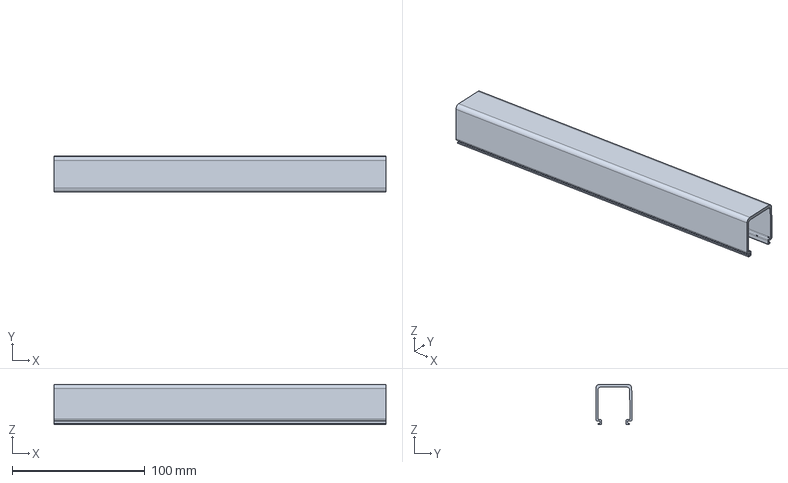
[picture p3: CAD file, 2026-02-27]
3d_models/Tube/Cable Management/cable_channel.FCStd
250.0 x 27.4 x 30.4 mm

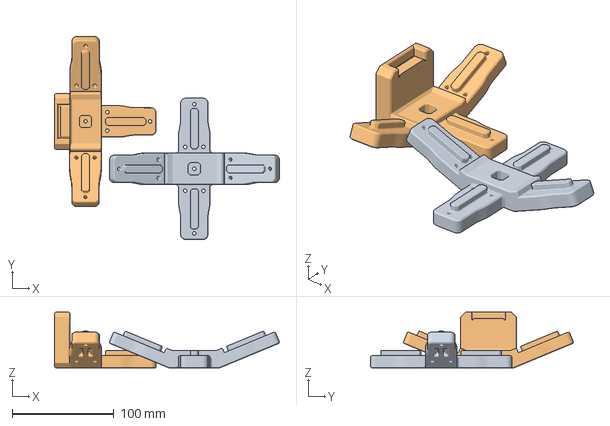
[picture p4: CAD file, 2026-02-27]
3d_models/Tube/Connectors/rlcv3_connector_cross_45°.3mf
221.3 x 199.7 x 54.8 mm

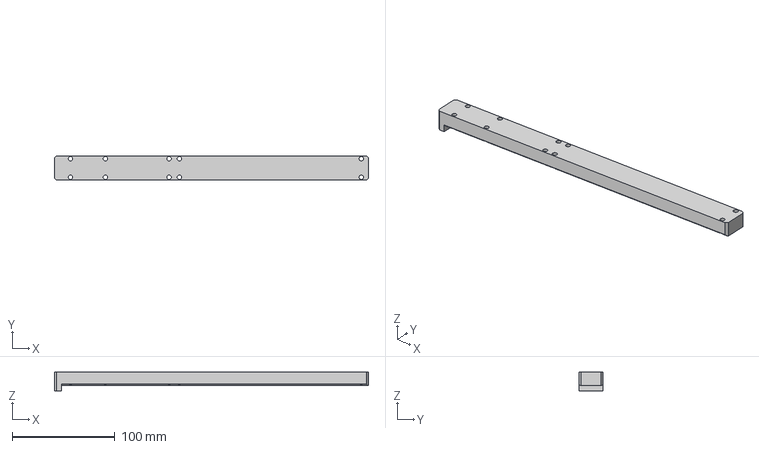
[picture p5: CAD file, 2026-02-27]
3d_models/Tube/Enclosure/drill_template.stp
305.5 x 23.7 x 18.0 mm

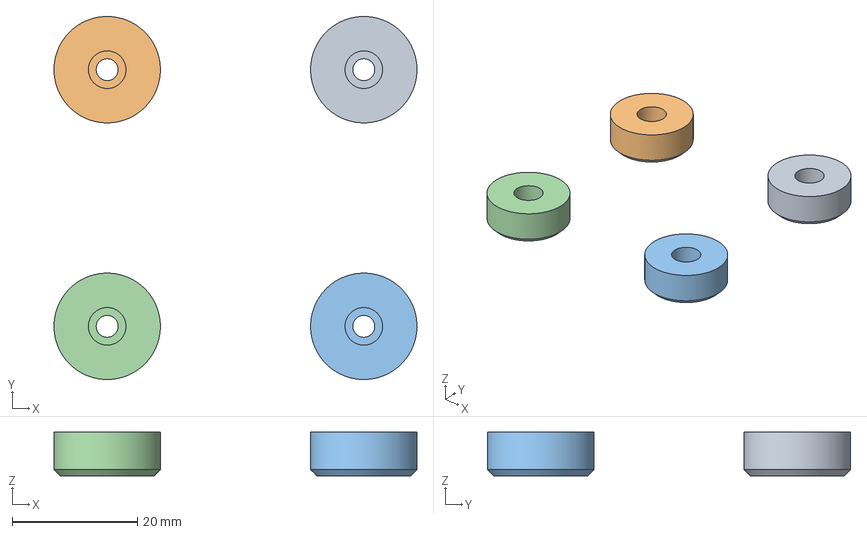
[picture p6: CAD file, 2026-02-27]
3d_models/Tube/Stand/floor_stand_feet.3mf
58.0 x 58.0 x 7.00 mm

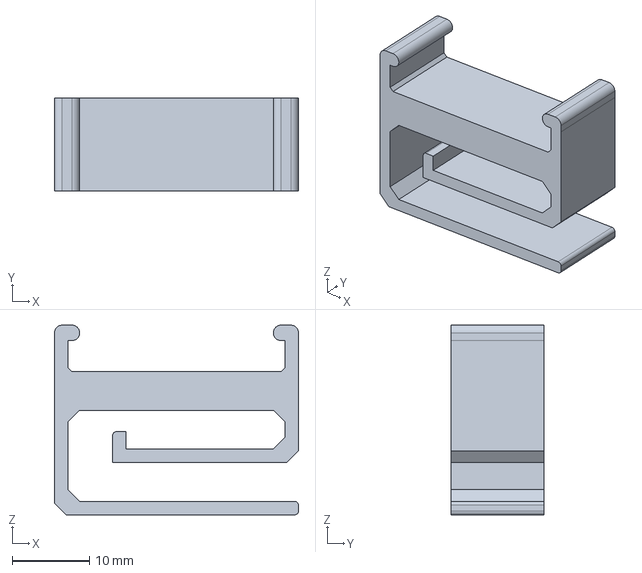
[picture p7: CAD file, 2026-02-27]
3d_models/Tube/Cable Management/cable_clip.FCStd
31.5 x 12.0 x 24.5 mm

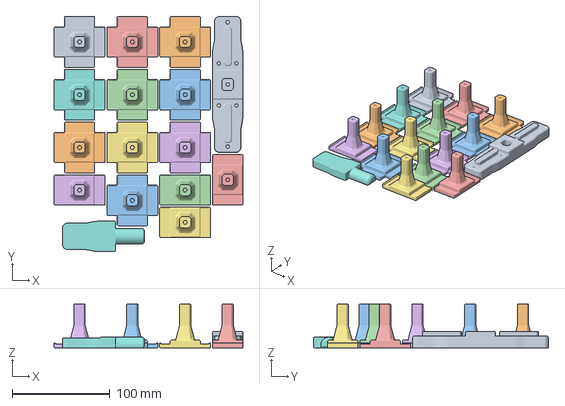
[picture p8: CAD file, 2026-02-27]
3d_models/Tube/Connectors/rlcv3_connector_clamp_2.3mf
193.0 x 240.3 x 44.9 mm

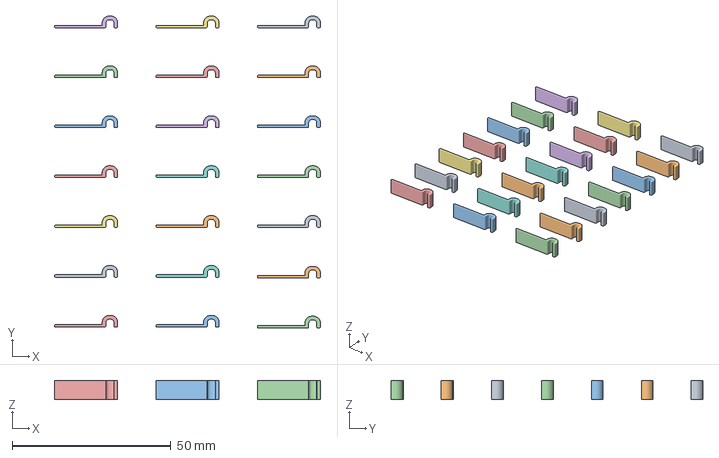
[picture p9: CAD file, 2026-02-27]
3d_models/Tube/Enclosure/rlcv3_cable_clip.3mf
83.7 x 98.1 x 6.00 mm

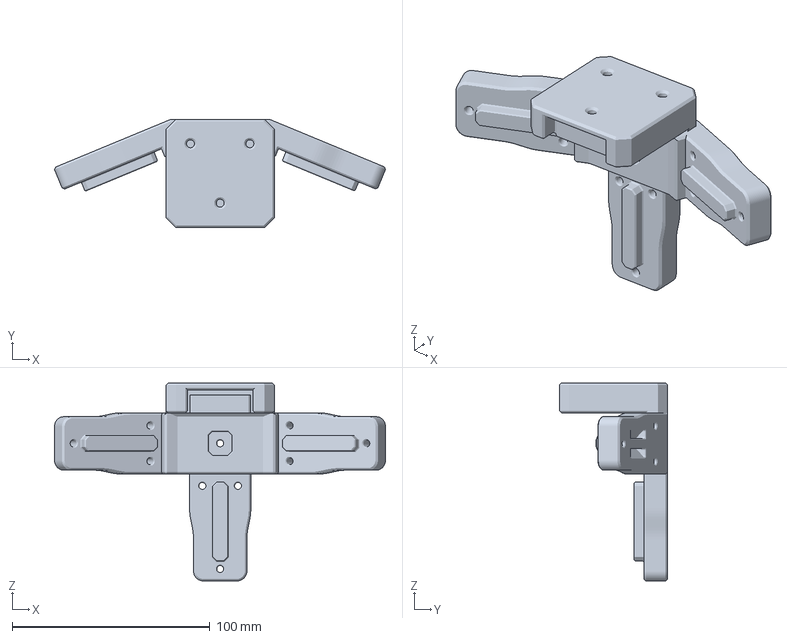
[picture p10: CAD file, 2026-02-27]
3d_models/Tube/Stand/floor_stand_interface_tube_t_section_45°.3mf
167.3 x 54.8 x 100.0 mm

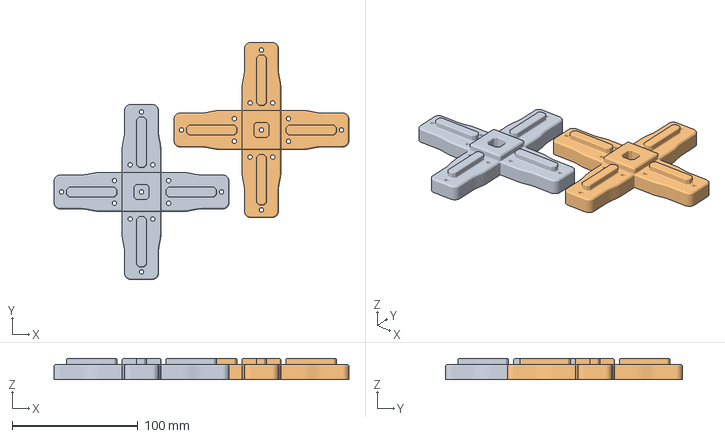
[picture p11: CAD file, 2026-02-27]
3d_models/Tube/Connectors/rlcv3_connector_cross.3mf
234.2 x 188.2 x 17.0 mm

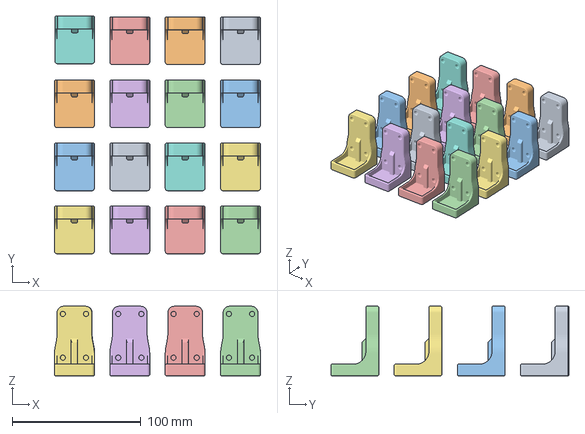
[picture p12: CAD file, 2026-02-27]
3d_models/Tube/Enclosure/rlcv3_end_cap.3mf
160.0 x 184.7 x 54.0 mm

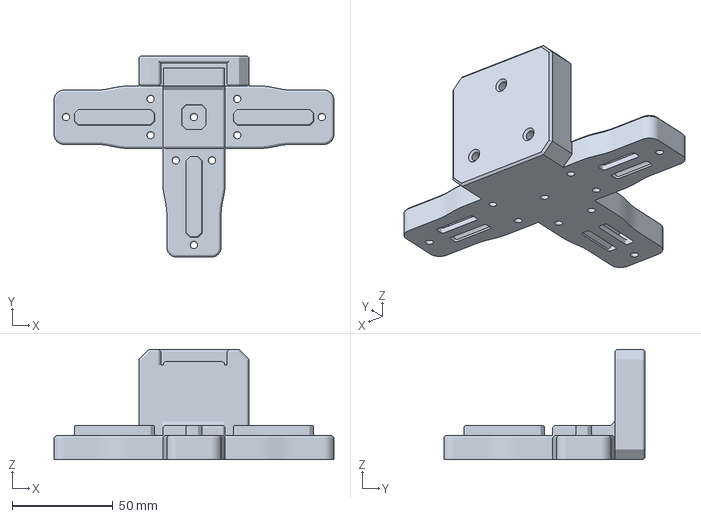
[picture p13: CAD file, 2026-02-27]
3d_models/Tube/Stand/floor_stand_interface_tube_t_section.3mf
139.0 x 100.0 x 54.8 mm

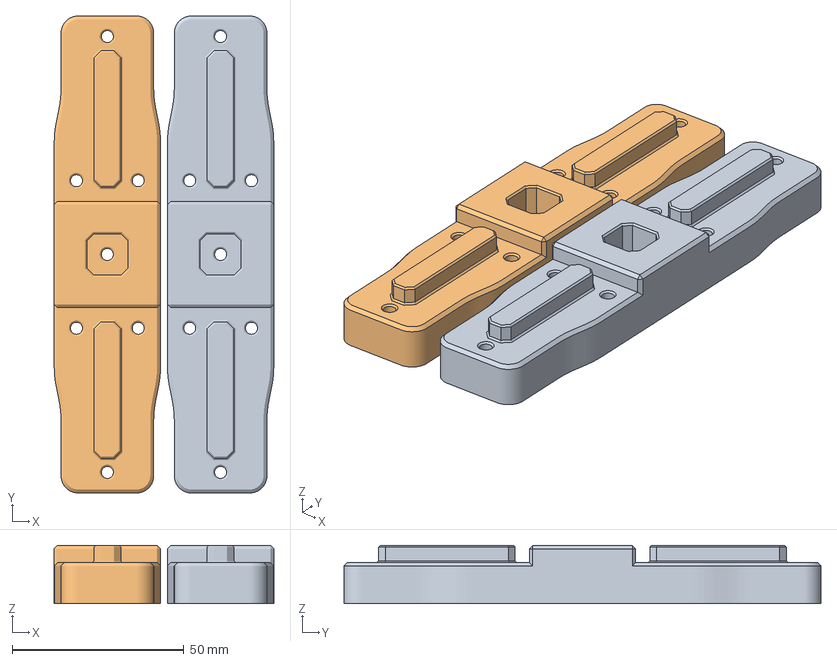
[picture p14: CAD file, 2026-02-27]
3d_models/Tube/Connectors/rlcv3_connector_2_straight.3mf
64.0 x 139.0 x 17.0 mm

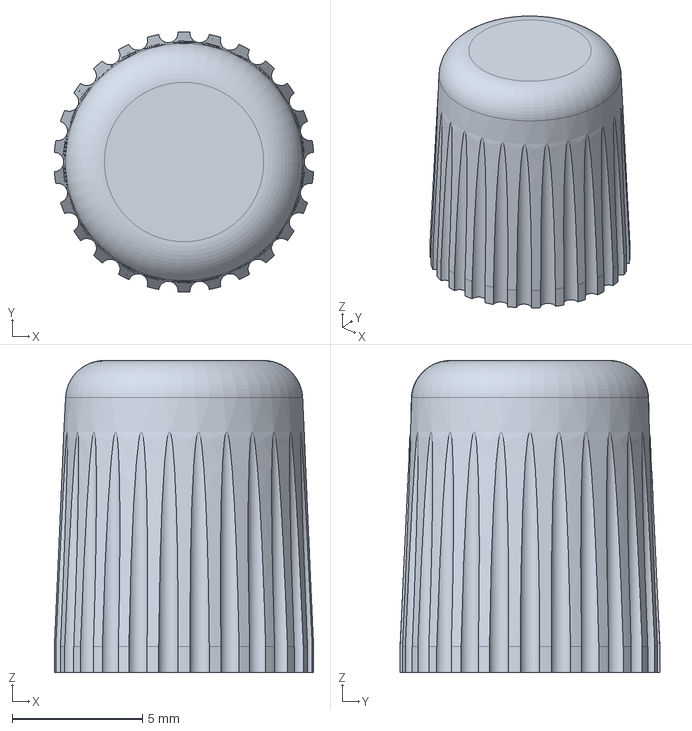
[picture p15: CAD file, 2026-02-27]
3d_models/Tube/Enclosure/rotary_encoder_knob_10mm.FCStd
9.97 x 10.00 x 12.0 mm

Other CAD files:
3d_models/Tube/Stand/floor_stand.FCStd
3d_models/Tube/Connectors/rlcv3_connector_clamp_3.3mf
3d_models/Tube/Enclosure/display_spacer.FCStd
3d_models/Tube/Stand/floor_stand_funnel_holder.3mf
3d_models/Tube/Cable Management/cable_channel.3mf
3d_models/Tube/Cable Management/cable_clip.3mf
3d_models/Tube/Connectors/rlcv3_connector_90_degree.3mf
3d_models/Tube/Connectors/rlcv3_connector_adapter_spots_connector.3mf
3d_models/Tube/Connectors/rlcv3_connector_clamp_4.3mf
3d_models/Tube/Connectors/rlcv3_connector_t_section.3mf
3d_models/Tube/Connectors/rlcv3_connector_t_section_45°.3mf
3d_models/Tube/Enclosure/display_spacer.3mf
3d_models/Tube/Enclosure/rlcv3_bottom.stp
3d_models/Tube/Enclosure/rlcv3_top.stp
3d_models/Tube/Enclosure/rotary_encoder_knob_10mm.3mf
3d_models/Tube/Stand/floor_stand.3mf
3d_models/Tube/Stand/floor_stand_funnel.3mf

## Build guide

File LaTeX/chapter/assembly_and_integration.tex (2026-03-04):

\section{Device Assembly} \label{sec:device_assebly}

\subsection{PCB Assembly}
The assembly process begins with the population of the \ac{PCB}.
To create a stable, level surface for applying solder paste, a jig made from spare boards is recommended.
Once the stencil is aligned, solder paste is applied evenly across the pads.
Next, the \ac{SMD} components are carefully placed using tweezers, with the exception of the \ac{MCU}, which is installed later.
The board is then reflowed using a heating plate or oven.

\begin{figure}[H]
	\centering
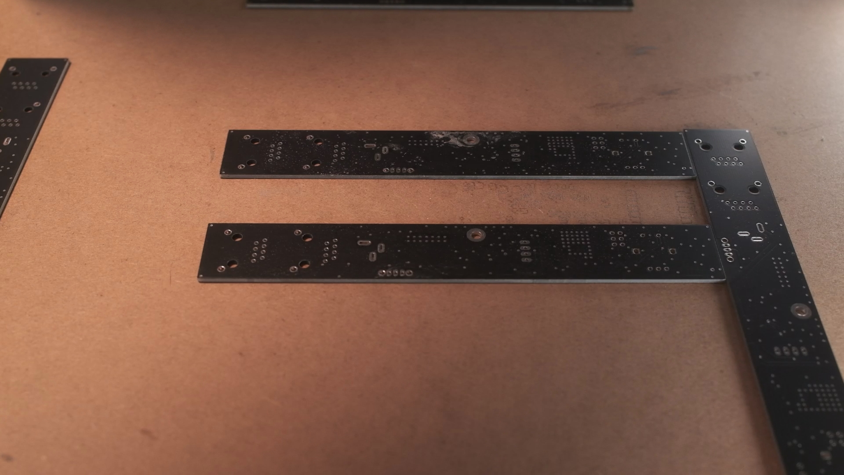
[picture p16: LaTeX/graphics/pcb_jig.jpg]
	
	\caption{Assembly jig of the PCB}
	\label{fig:pcb_assembly}
\end{figure}

After the reflow process, the \ac{DC} jack is soldered manually.
Before proceeding with sensitive components, a 24V power source is connected to verify the 5V regulator's output with a multimeter; ensuring a stable voltage here is critical.
Once verified, the remaining \ac{THT} components, including the \ac{MCU} and pin headers, are soldered.
Special care should be taken to align the display's pin header at a precise 90-degree angle.
Finally, flux residues are cleaned using \ac{IPA}, and the \ac{LED} strip is prepared by cutting it to one-meter segments and desoldering any factory-installed wires.

\subsection{Firmware Configuration and Flashing}
To configure the software, download the firmware source code from the project repository and open it in the Arduino \ac{IDE}.
Ensure the Espressif board manager \ac{URL} is added to the preferences, then install the ESP32 board package (Version 3.30.3) via the Boards Manager.
Select \texttt{XIAO\_ESP32C3} as the target board.
Before flashing, adjust any necessary configuration parameters, such as the pixel count, in \texttt{config.h}.
Connect the board via \ac{USB}-C and upload the firmware; a successful flash is confirmed by the "Done uploading" message in the console.

\subsection{Mechanical Assembly}
\subsubsection{Preparation}
The enclosure components—including the housing bottom, top part, endcaps, and rotary encoder knob—are fabricated using \ac{FDM} printing.
M3 threaded inserts are then installed into the bottom housing and endcaps using a soldering iron, ensuring they sit flush with the surface.
The aluminum profile is cut into two one-meter sections.
Using the provided drill template, mounting points are marked with a center punch and drilled using a 3.5 mm bit.

\subsubsection{Wiring and Integration}
Wires are prepared as follows:
\begin{itemize}
	\item Data: 15 cm, 20 \ac{AWG}
	\item Power: 5 cm, 18 \ac{AWG}
\end{itemize}
Pre-tin the wire ends and solder them to the \ac{LED} strip.
The \ac{OLED} display is then attached to the \ac{PCB} using a spacer and double-sided tape for alignment. \\

Secure the end caps and bottom housing to the aluminum profile using M3 bolts, and mount the \ac{PCB} to the bottom housing using two 8 mm standoffs.
Install the \ac{LED} strip into the profile, routing the data line through a cable clip for a clean look.
Feed the wires through to the rear, strip the insulation, and solder them to the corresponding \ac{PCB} pads. \\

Install the antenna into the top housing and connect it to the ESP32, ensuring it does not interfere with the onboard buttons.
Secure the top cover to the standoffs and press the 3D-printed knob onto the rotary encoder shaft.
To finish the assembly, slide the diffuser under the endcaps and snap it into place.

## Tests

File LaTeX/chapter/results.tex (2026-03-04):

\section{Results}
\label{sec:results}
\subsection{Hardware Performance}
\label{subsec:hardware_performance}

\subsubsection{Thermal Analysis}
\label{subsec:thermal_analysis}
The Light Tube V3 and Spotlight variants maintain safe operating temperatures.
The aluminum profile of the Tube acts as an effective passive heatsink, while the Spotlight's active cooling is sufficient.
No critical heat buildup occurs at maximum brightness.
The Panel variant overheats.
Direct active cooling of the PCB is insufficient without a dedicated heatsink.
Future designs require a heatsink and fan.
The five addressable sections provide limited utility.
Replacing them with a single section of high-power, MOSFET-controlled LEDs is recommended to eliminate the quiescent current draw of addressable ICs.

\subsubsection{Power Stability}
\label{subsec:power_stability}
The 5V rail remains stable under full logic load (Art-Net and Display active).
LED strip brightness does not affect the 5V rail.
Addressable strips (WS2815) draw power from the 12V/24V input, bypassing the 5V buck converter.
MOSFET gate switching current is negligible.

\subsection{Software Performance}
\label{subsec:software_performance}
\subsubsection{Responsiveness}
\label{subsec:responsiveness}
Art-Net over Wi-Fi exhibits visible latency.
It is unsuitable for live music synchronization.
Wired DMX512 shows no perceptible latency and is validated for live performance.
The DMX driver occasionally fails upon bus connection, requiring a microcontroller reset.
Post-reset operation is stable.

\subsection{Overall System Functionality for Each Product}
\label{subsec:overall_system_functionality}
\subsubsection{Light Tube V2 (PWM Control)}
\label{subsubsec:light_tube_v2_results}
The V2 variant is considered deprecated, mainly due to the enclosure design. 
Integrating the controller into the end cap meant there were no connection points for building "light sculptures".
Also, controlling the whole tube as just one segment via MOSFETs felt visually limited.

\subsubsection{Light Tube V3 (RGB IC Control)}
\label{subsubsec:light_tube_v3_results}
The V3 is a solid improvement. 
The addressable LED strips provide much better visuals.
The "Screw it!" connection design is a highlight, offering the support needed for modular, multi-tube builds.

\subsubsection{Panel Light}
\label{subsubsec:panel_light_results}
The Panel functions, but you have to be careful with high brightness levels. 
The internal logic—sending I2C data to control addressable LEDs—ended up being overly complex for what it achieves.

\subsubsection{Spot Light}
\label{subsubsec:spot_light_results}
The Spotlight works well. The lens focuses the single COB LED effectively, and the 3D-printed diffusion cube blends the colors nicely.
The aluminum heatsink and fan keep it cool enough, and having just one control segment is exactly what you need for a spot.

\subsection{Enclosure Quality and Durability}
\label{subsec:enclosure_quality}
The 3D-printed components have proven to be robust. 
They hold up well under normal use and provide good overall stability for the fixtures. 
The heat-set inserts are a key factor here; they offer enough strength for the "Screw it!" connection system to work reliably without stripping or pulling out. 
Although the parts haven't been purposely tested to failure, no mechanical failures have occurred during assembly or operation so far.

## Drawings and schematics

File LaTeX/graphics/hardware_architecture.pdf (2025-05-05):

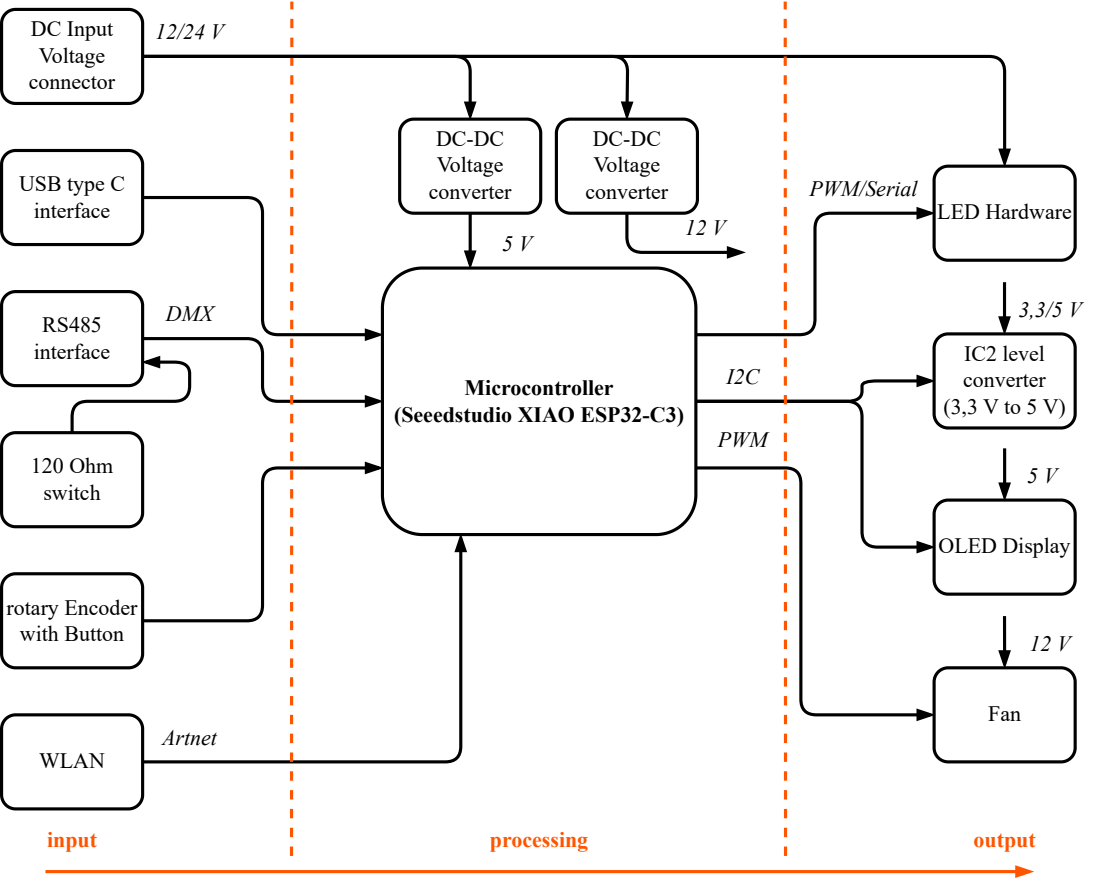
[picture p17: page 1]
DC Input Voltage connector; DC-DC Voltage converter; LED Hardware; Microcontroller (Seeedstudio XIAO ESP32-C3); USB type C interface; RS485 interface; 120 Ohm switch; IC2 level converter (3,3 V to 5 V); rotary Encoder with Button; OLED Display; DMX; PWM/Serial; WLAN; Artnet; input; processing; output; Fan; PWM

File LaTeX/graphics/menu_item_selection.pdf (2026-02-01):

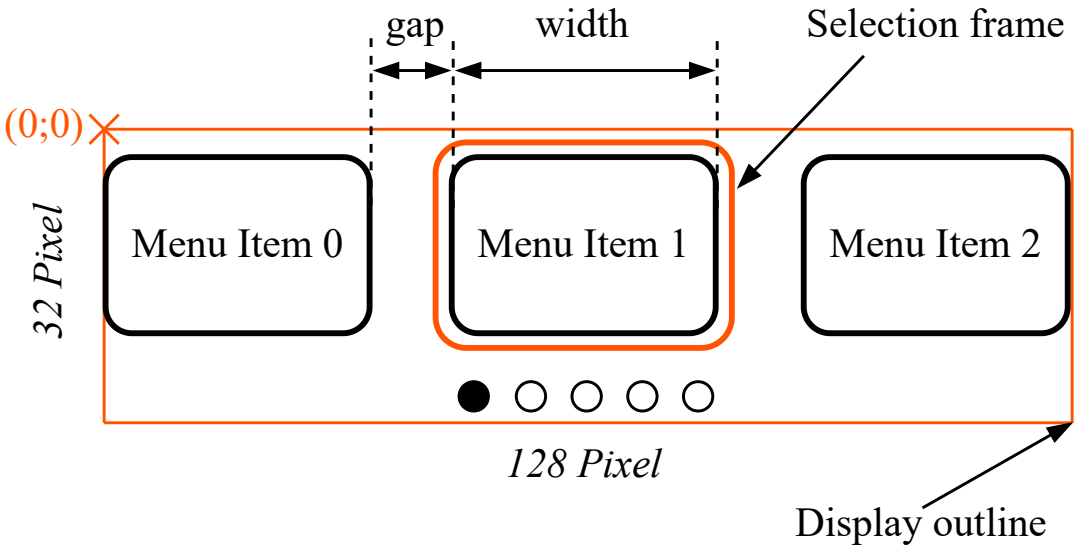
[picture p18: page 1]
Menu Item 0; Menu Item 1; Menu Item 2; gap; width; Selection frame; Display outline; 128 Pixel; 32 Pixel

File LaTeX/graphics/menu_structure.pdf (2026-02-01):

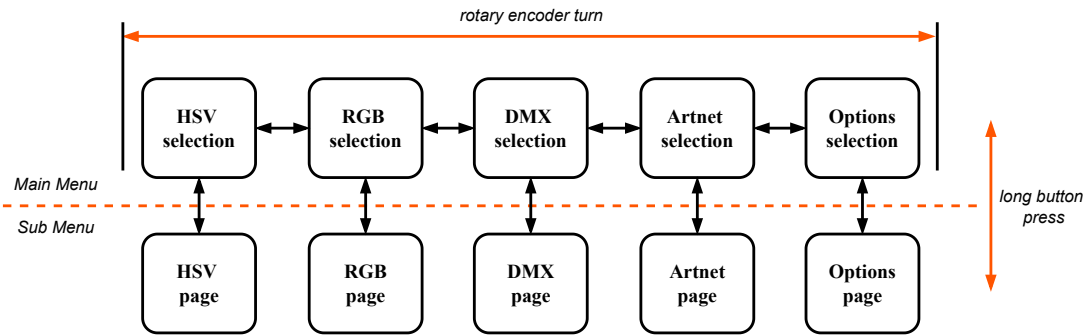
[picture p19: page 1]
DMX selection; RGB selection; HSV selection; Artnet selection; Options selection; HSV page; RGB page; DMX page; Artnet page; Options page; Main Menu; Sub Menu; long button press

rotary encoder turn

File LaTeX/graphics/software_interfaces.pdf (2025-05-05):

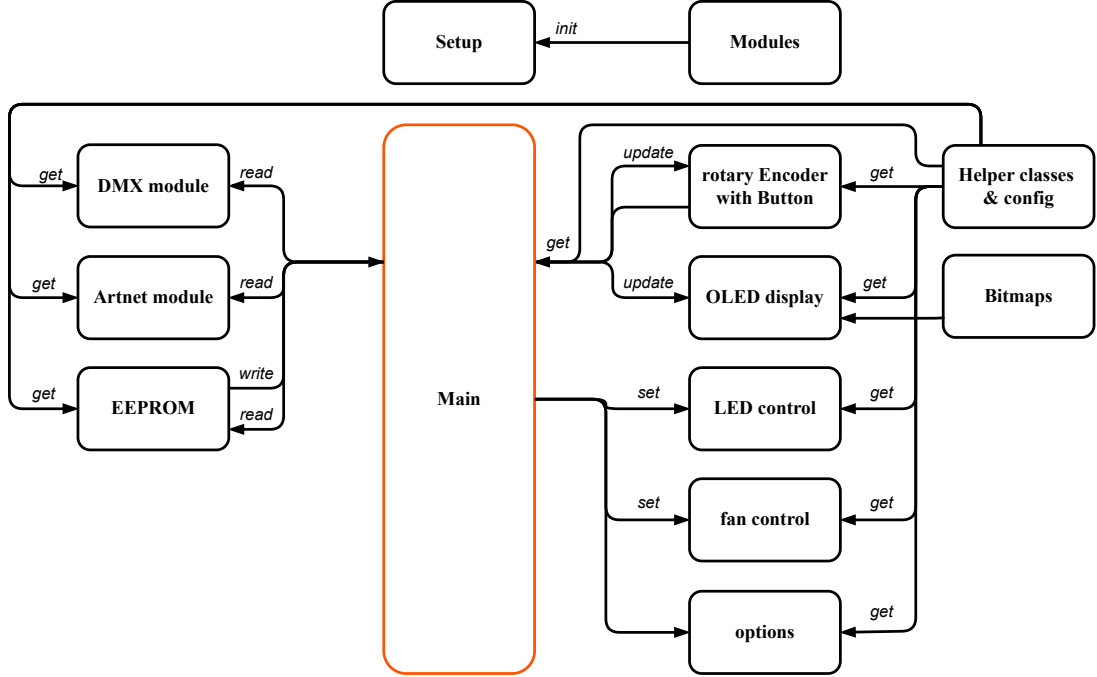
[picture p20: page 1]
Setup; Modules; rotary Encoder with Button; update; OLED display; LED control; set; fan control; Helper classes & config; Bitmaps; get; Main; init; DMX module; read; Artnet module; EEPROM; write; options

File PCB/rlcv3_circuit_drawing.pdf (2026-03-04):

# 2 D²

# A_R120 VIN_D FB SW

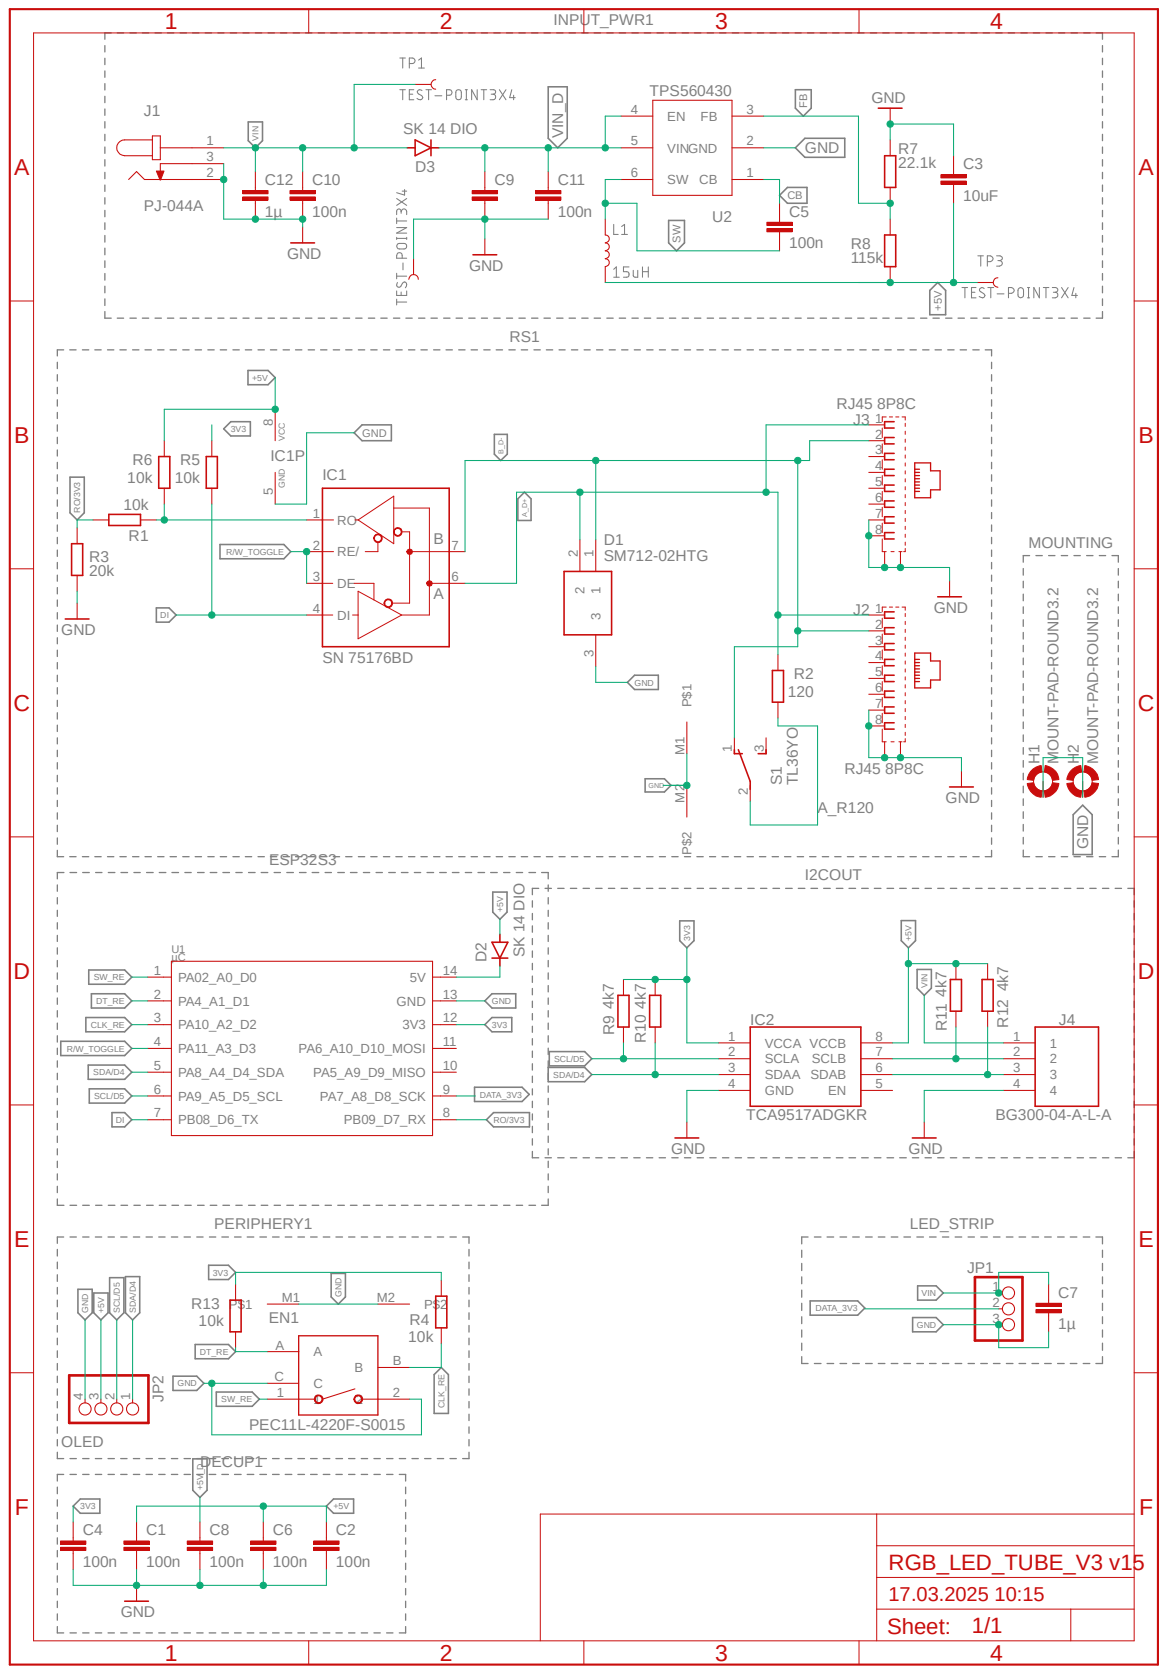
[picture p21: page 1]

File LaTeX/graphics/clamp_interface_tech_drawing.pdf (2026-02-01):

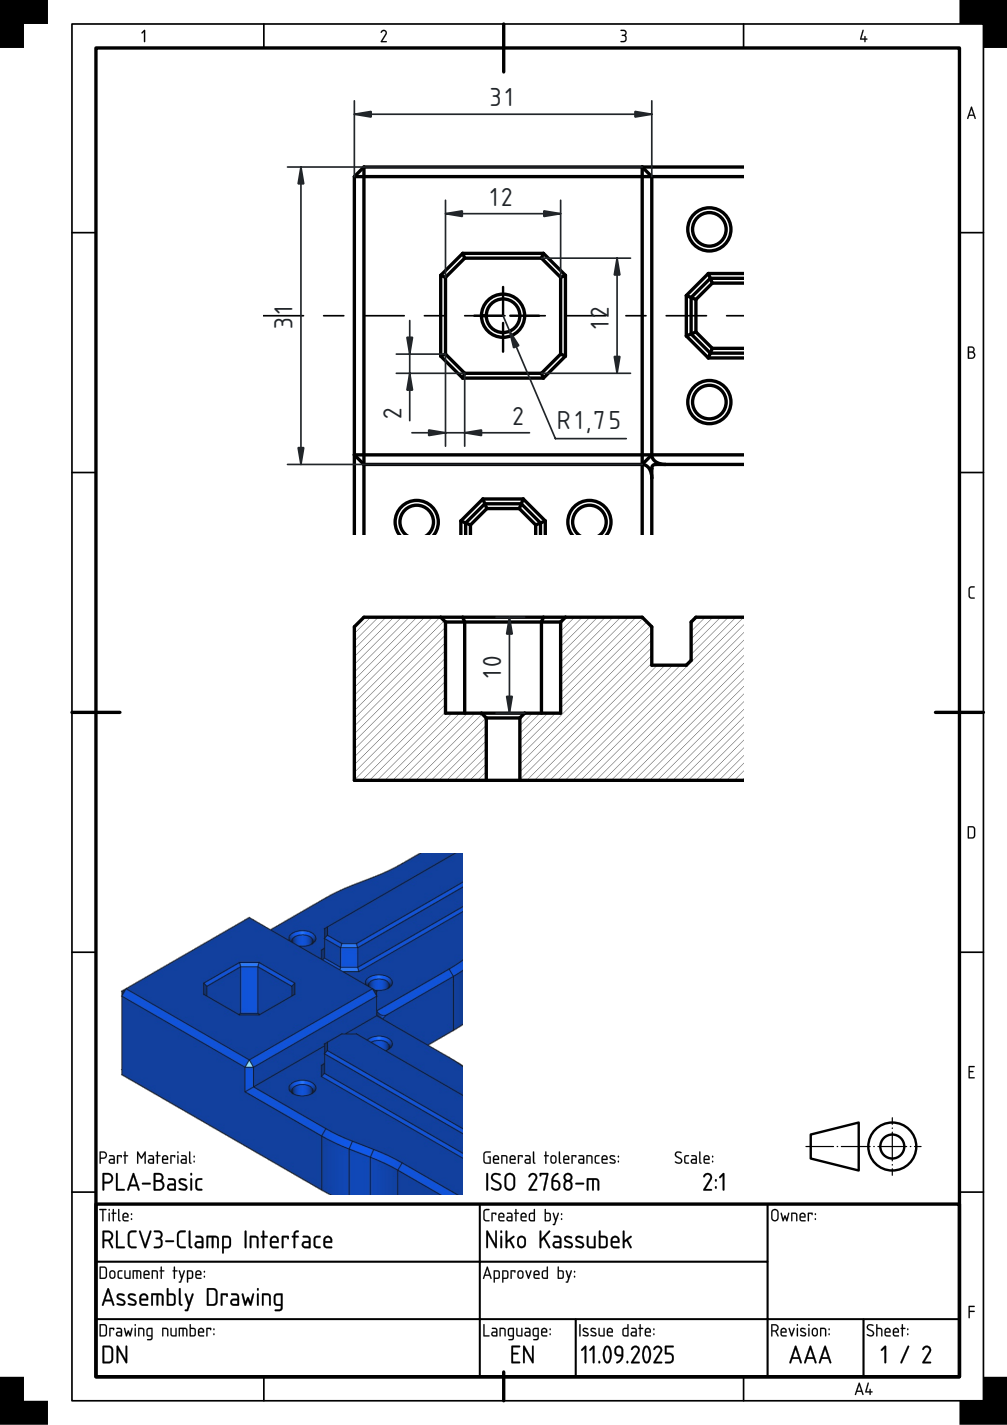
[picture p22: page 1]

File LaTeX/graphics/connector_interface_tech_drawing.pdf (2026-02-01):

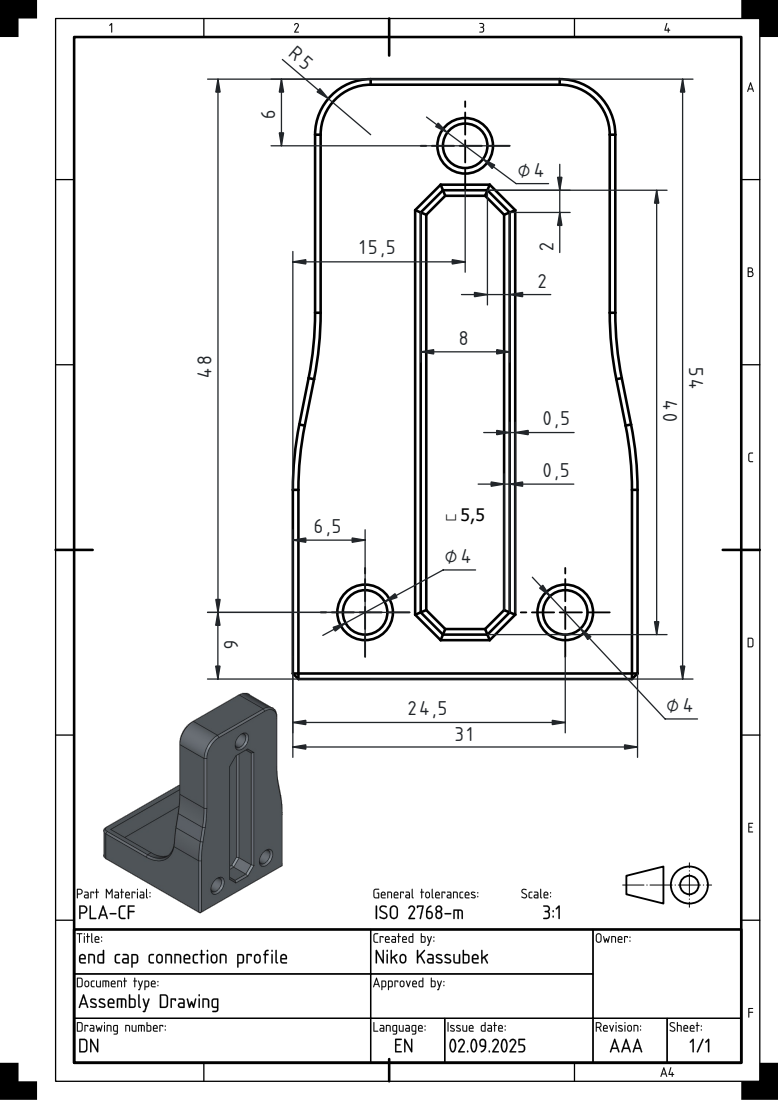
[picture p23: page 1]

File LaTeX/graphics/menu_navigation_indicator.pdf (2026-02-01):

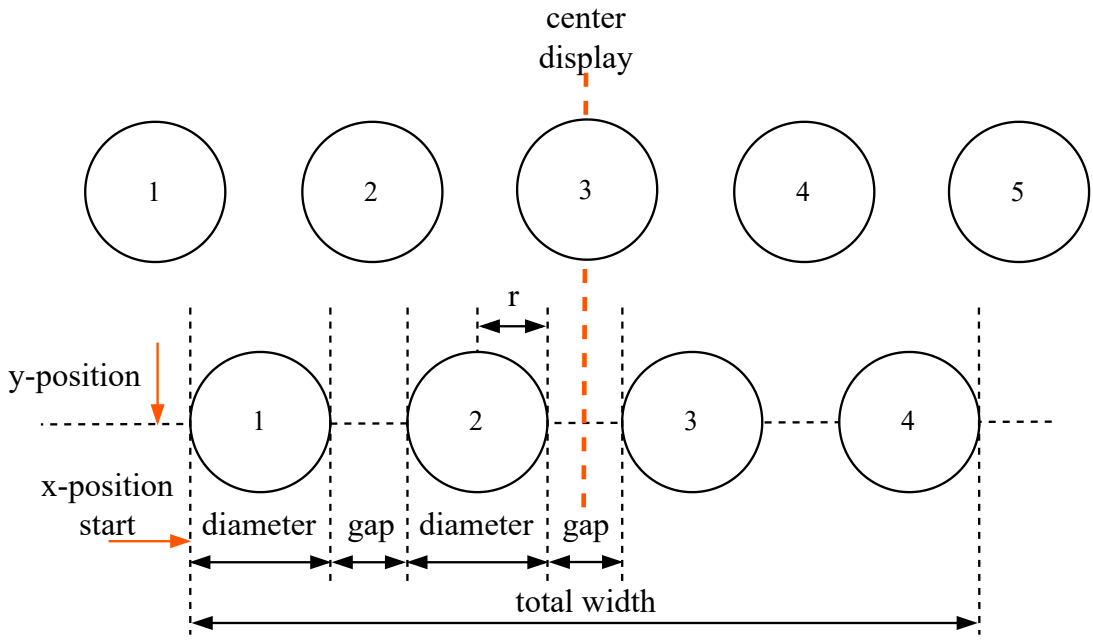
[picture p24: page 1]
diameter gap; center display; y-position; x-position start; total width

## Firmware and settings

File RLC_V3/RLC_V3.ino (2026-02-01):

/*

  Project:          RLC_V3
  Author:           Niko Kassubek
  Microcontroller:  SeeedStudio XIAO ESP32-C3

*/

/*
  Architecture Overview:
  This project utilizes a hybrid Event-Driven architecture combined with a polling loop for real-time tasks.

  1. Event System: User inputs (Rotary Encoder), Timers, and System changes generate events posted to a queue (EventManager).
  2. Event Handler: The main loop processes these events to update the application state (Menu, LED values, Settings) and trigger UI updates.
  3. Continuous Tasks: High-bandwidth tasks like DMX and ArtNet processing run continuously in the main loop to ensure low latency.
  4. Modularity: Hardware abstraction layers exist for Display, LEDs, DMX, and NVM (EEPROM), keeping the main logic decoupled from hardware specifics.
*/

/* ************ LIBRARY DEPENDENCIES ************ **

  Make sure, to have these library versions installed,
  otherwise it may break this code!

  esp core:             version 3.30.3

  Adafruit GFX Library: version 1.12.1
  Adafruit NeoPixel:    version 1.13.0
  Adafruit SSD1306:     version 2.5.14
  ArtnetWifi:           version 1.6.1
  EncoderButton:        version 1.0.6
  FastLED:              version 3.9.16
  esp_dmx:              version 4.1.0 -> needs fix https://github.com/someweisguy/esp_dmx/issues/181#issuecomment-2619261884

** ************ LIBRARY DEPENDENCIES ************ */

#include "continuous_tasks.h"
#include "display.h"
#include "dmx.h"
#include "event_handler.h"
#include "event_manager.h"
#include "leds.h"
#include "nvm.h"
#include "rlc_artnet.h"
#include "rotary_encoder_events.h"
#include "segments.h"
#include "soft_timer.h"

#ifdef FAN_USAGE
#include "fan_control.h"
#endif

#include "common.h"

// --- Globals: State ---
bool artnet_data = false;

// --- Globals: Objects ---
C_HSV hsv_val(STD_HUE, STD_SAT, STD_VAL);
C_RGB rgb_val(STD_RED, STD_GREEN, STD_BLUE);
rlc_artnet artnet_var;
menu_structure main_sw;
segments seg;
Adafruit_SSD1306 display(SCREEN_WIDTH, SCREEN_HEIGHT, &Wire, OLED_RESET);
settings_menu option_menu;

event_t event;

#ifdef FAN_USAGE
fan_control fan;
#endif

void startup_wrapper();
void startup_wrapper() {
  uint8_t current_deepness = main_sw.get_deepness();
  uint8_t main_state = main_sw.get_current();
  int steps = STARTUP_TIME / FRAME_DELAY;

  if (current_deepness == SUB_MENU) {
    uint8_t target_val = hsv_val.get_val();

    for (int i = 0; i <= steps; i++) {
      display_startup(display);
      if (main_state == HSV_PAGE) {
        C_HSV temp_hsv = hsv_val;
        int val = map(i, 0, steps, 0, target_val);
        temp_hsv.set_val(val);
        hsv_out(temp_hsv);
      } else if (RGB_PAGE == main_state) {
        int factor = map(i, 0, steps, 0, 255);
        rgb_out(rgb_val.get_rgb(), factor);
      }
      delay(FRAME_DELAY);
    }
    if (main_state == ARTNET_PAGE) {
      artnet_var.connect_wifi();
      artnet_var.set_current_fsm(CONNECTING);
      TimerManager.start(TIMER_CONNECTING_DOTS);
    }
  } else {
    for (int i = 0; i < steps; i++) {
      display_startup(display);
      delay(FRAME_DELAY);
    }
  }
}

void on_artnet_frame(uint16_t universe, uint16_t length, uint8_t sequence, uint8_t* data) {
  uint16_t current_universe = artnet_var.get_start_universe();
  if (universe == current_universe) {
    artnet_var.set_current_universe(data);
  } else if (universe == (current_universe + 1)) {
    artnet_var.set_next_universe(data);
  }
  artnet_data = true;
}

void setup() {
// init fan instantly
#ifdef DEBUGGING_ENABLED
  Serial.begin(115200);
#endif

#ifdef FAN_USAGE
  fan.init_fan();
  DEBUG_PRINTLN("FAN INIT DONE");
#endif

  // sanity delay
  delay(500);

  DEBUG_PRINTLN("Startup");

  // init event system
  event_manager.init();
  DEBUG_PRINTLN("EVENT MANAGER INIT DONE");

  TimerManager.init();
  DEBUG_PRINTLN("SOFT TIMER INIT DONE");

  // init all classes and functions
  main_sw.init();
  DEBUG_PRINTLN("MAIN INIT DONE");

  init_eeprom();
  DEBUG_PRINTLN("EEPROM INIT DONE");

  init_display(display);
  DEBUG_PRINTLN("DISPLAY INIT DONE");

  init_led();
  DEBUG_PRINTLN("LED INIT DONE");

  init_encoder_with_events();
  DEBUG_PRINTLN("ENCODER INIT DONE");

  dmx_val.install_dmx();
  DEBUG_PRINTLN("DMX INIT DONE");

  seg.init_segments();
  DEBUG_PRINTLN("SEGMENT INIT DONE");

  artnet_var.init(on_artnet_frame);
  DEBUG_PRINTLN("ARTNET INIT DONE");

  // read non volatile memory and set variables accordingly
  read_eeprom(hsv_val, rgb_val, dmx_val, main_sw, artnet_var, seg);

  startup_wrapper();

  // wake up display and Start display standby timer
  event_manager.post(EVT_DISPLAY_WAKE);
  TimerManager.start(TIMER_DISPLAY_STANDBY);

#ifdef FAN_USAGE
  TimerManager.start(TIMER_UPDATE_FAN);
  if (main_sw.get_deepness() == SUB_MENU) {
    if (main_sw.get_current() == HSV_PAGE) {
      fan.calc_hsv_speed(hsv_val);
    } else if (main_sw.get_current() == RGB_PAGE) {
      fan.calc_rgb_speed(rgb_val.get_rgb());
    }
  }
#endif

  DEBUG_PRINTLN("Startup complete.");
}

void loop() {
  enc_button.update();

  // Update timers (posts events on expiry)
  TimerManager.update();

  // Process all pending events
  if (event_manager.get_event(&event)) {
    process_event(&event);
  }

  // Handle continuous tasks (DMX, Artnet - NOT event driven)
  handle_continuous_tasks();
}

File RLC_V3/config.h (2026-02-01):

#if !defined(CONFIG_H)
#define CONFIG_H

// first digit:  increment if breaking change occures
// last digit:   increment before each pull request for new feature or bug fix to main branch
#define RLCV3_FIRMWARE_VERSION "2.0"

// Comment out this line to disable all debug output
// #define DEBUGGING_ENABLED

#ifdef DEBUGGING_ENABLED
#define DEBUG_PRINT(...) Serial.print(__VA_ARGS__)
#define DEBUG_PRINTLN(...) Serial.println(__VA_ARGS__)
#define DEBUG_PRINTF(...) Serial.printf(__VA_ARGS__)
#else
// If disabled, these macros are replaced with nothing
#define DEBUG_PRINT(...)
#define DEBUG_PRINTLN(...)
#define DEBUG_PRINTF(...)
#endif

// ----------------------------------------------------------------------------------------------------------------------------------------
//
//                   ONLY UNCOMMENT ONE OF THE OPTIONS
//
#define RGB_IC_TUBE  // Sets the mode for hardware to RGB_IC: usage with led strip like WS2815, WS2812B
// #define RGB_TUBE // Sets the mode for hardware to RGB: usage with rgb led strip driven with mosfets
// #define PANEL // Sets the mode for hardware to PANEL: usage with slave deveices controlled via i2c and cooling fan
// #define SPOT // Sets the mode for hardware to SPOT: usage with a single cob rgb led and cooling fan
// ----------------------------------------------------------------------------------------------------------------------------------------

// check if zero or more than one config is selected
#if defined(RGB_IC_TUBE) + defined(RGB_TUBE) + defined(PANEL) + defined(SPOT) != 1
#error "Zero or more than one hardware config is active. Check the hardware config settings in the 'config.h' file."
#endif

// ----------------------------------------------------------------------------------------------------------------------------------------
//
//                   CONFIGURATION OF THE HARDWARE FROM THE SELECTION ABOVE
//
// OPTIONS:
// -> led output type, dependend on the led strip / hardware
//    -> LED_OUT_RGBIC: addressable led strip
//    -> LED_OUT_MOSFET: rgb control with mosfets/transitors via 8 bit PWM
//    -> LED_OUT_I2C: rgb + dimmer values are sent via I2C to slave devices
// -> NUM_PIXEL: number of the pixels of the LED strip: integer value >= 1 >= 170
//    (170 ~= (512 - 1) / 3) (170 ~= (DMX_UNIVERSE - DIMMER_CHANNEL) / RGB)
//    for rgb non addressable strip NUM_PIXEL of 1 is needed
// -> fan controll:
//    -> FAN_USAGE: defined if a fan is required with the hardware
//    -> FAN_MAX_SPEED: required if FAN_USAGE is defined -> maximum 8 bit PWM value of the fan
//    -> FAN_MIN_SPEED: required if FAN_USAGE is defined -> minimum 8 bit PWM value of the fan
//    -> ZERO_PWM:  required if FAN_USAGE is defined -> true: values below FAN_MIN_SPEED turnes the fan off;
//                                                      false: values below FAN_MIN_SPEED are clamped to FAN_MIN_SPEED value
// ----------------------------------------------------------------------------------------------------------------------------------------
#ifdef RGB_IC_TUBE
#define NO_FAN
#define LED_OUT_RGBIC
#define NUM_PIXEL 24
#endif

#ifdef RGB_TUBE
#define NO_FAN
#define LED_OUT_MOSFET
#define RED_PIN D10
#define GREEN_PIN D9
#define BLUE_PIN D8
#define NUM_PIXEL 1
#endif

#ifdef PANEL
#define LED_OUT_I2C

#define FAN_USAGE
#define PWM_PIN D8
#define FAN_MAX_SPEED 225
#define FAN_MIN_SPEED 60
#define FAN_ZERO_RPM false

#define NUM_PIXEL 5
#endif

#ifdef SPOT
#define LED_OUT_MOSFET
#define RED_PIN D10
#define GREEN_PIN D8
#define BLUE_PIN D9

#define FAN_USAGE
#define PWM_PIN D3
#define FAN_MAX_SPEED 255
#define FAN_MIN_SPEED 75
#define FAN_ZERO_RPM true

#define NUM_PIXEL 1
#endif

#ifdef NO_FAN
#define PWM_PIN NOT_A_PIN
#define FAN_MAX_SPEED 0
#define FAN_MIN_SPEED 0
#define FAN_ZERO_RPM false
#endif

// check correct number of pixel
#if defined(NUM_PIXEL) == 0 || defined(NUM_PIXEL) > 170
#error "Pixel number is below 1 or above 170. Adjust NUM_PIXEL parameter."
#endif

// check if fan control config is correct
#if defined(FAN_USAGE) && (!defined(PWM_PIN) || !defined(FAN_MAX_SPEED) || !defined(FAN_MIN_SPEED) || !defined(FAN_ZERO_RPM))
#error "With FAN_USAGE active, min/max speed and zero rpm mode have to be defined."
#endif

// check if pwm led output config is correct
#if defined(LED_OUT_MOSFET) && (!defined(RED_PIN) || !defined(GREEN_PIN) || !defined(BLUE_PIN))
#error "With LED_OUT_MOSFET active, red, green and blue pins have to be defined."
#endif
#endif  // CONFIG_H

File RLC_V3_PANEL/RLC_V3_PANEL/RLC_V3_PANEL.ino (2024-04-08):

#include "tinyNeoPixelModded.h"
#include <Wire.h>
// I2C for Attiny
// Changed buffer size to 16 Byte, otherwise the 402 Controller runs out of RAM
// https://github.com/SpenceKonde/megaTinyCore/tree/master/megaavr/libraries/Wire

// NeoPixel for Attiny
// Modified code to output one Color for all Pixel to save up RAM
// Only works with 16 Mhz clock speed

//    Pinout AtTiny402
//          ____
// 1 VDD  -|    |-  8 GND
// 2 PA6  -|    |-  7 PA3
// 3 PA7  -|    |-  6 PA0 (UPDI)
// 4 PA1  -|____|-  5 PA2

#define DATA_OUT PIN_PA7
#define LED_PIN PIN_PA6
#define SDA_PIN PIN_PA1
#define SCL_PIN PIN_PA2
#define NUM_PIXEL 75

// Select Slave Adress
// #define HW_INDEX_0 0
#define HW_INDEX_1 1
// #define HW_INDEX_2 2
// #define HW_INDEX_3 3
// #define HW_INDEX_4 4

#ifdef HW_INDEX_0
#define ADDRESS 0x08
#endif

#ifdef HW_INDEX_1
#define ADDRESS 0x09
#endif

#ifdef HW_INDEX_2
#define ADDRESS 0x0A
#endif

#ifdef HW_INDEX_3
#define ADDRESS 0x0B
#endif

#ifdef HW_INDEX_4
#define ADDRESS 0x0C
#endif

// struct for storing incoming data
struct rgb_data {
  uint8_t red;
  uint8_t green;
  uint8_t blue;
};

// For WS2815 no dedicated Chipset in library, therefore the standart is used
tinyNeoPixelModded leds = tinyNeoPixelModded(1, PIN_PA7);
rgb_data data;

void onReceive(int len) {
  data.red = Wire.read();
  data.green = Wire.read();
  data.blue = Wire.read();
  leds.setPixelColor(0, data.red, data.green, data.blue);
  leds.show(NUM_PIXEL);
}

void setup() {
  // sanity delay
  delay(2000);
  // begin with standart pins
  // PA1 (4) and PA2 (5)
  Wire.onReceive(onReceive);
  Wire.begin((uint8_t)ADDRESS);

  leds.begin();
}

void loop() {
}

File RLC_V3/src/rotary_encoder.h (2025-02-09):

#ifndef ROTARY_ENCODER_H
#define ROTARY_ENCODER_H
// https://github.com/Stutchbury/EncoderButton Encoder Libary
#include <EncoderButton.h>

// These defines are used to specify the pin numbers for the switch,
// data, and clock pins of the rotary encoder.

// The pin number for the switch pin of the rotary encoder
// the EncoderButton libary sets this pin to pull-up
#define SW_PIN D0

// The pin number for the CLK (clock) pin of the rotary encoder
#define CLK_PIN D1

// The pin number for the DT (data) pin of the rotary encoder
#define DT_PIN D2

#define LONG_PRESS_TIME 750
#define ACCERLERATION_SPEED 75

/**
 * Initialize the rotary encoder module with the specified EncoderButton object.
 *
 * @param eb: The EncoderButton object to use for handling button events.
 */
void init_encoder(EncoderButton &eb);

/**
 * Handle the encoder event.
 *
 * @param eb: The EncoderButton object that generated the event.
 */
void encoder_handler(EncoderButton &eb);

/**
 * Get the current encoder value and reset it.
 *
 * @return The current encoder value.
 */
int16_t get_encoder_val();

/**
 * Handle the long press event.
 *
 * @param eb: The EncoderButton object that generated the event.
 */
void long_press_handler(EncoderButton &eb);

/**
 * Get the state of the long press flag.
 *
 * @return The state of the long press flag.
 */
bool get_long_press();

/**
 * Set the state of the long press flag.
 *
 * @param state: The state to set the long press flag to.
 */
void set_long_press(bool state);

/**
 * Handle the press event.
 *
 * @param eb: The EncoderButton object that generated the event.
 */
void press_handler(EncoderButton &eb);

/**
 * Get the state of the press flag.
 *
 * @return The state of the press flag.
 */
bool get_press_state();

/**
 * Set the state of the press flag.
 *
 * @param state: The state to set the press flag to.
 */
void set_press_state(bool state);

/**
 * Handle the double press event.
 *
 * @param eb: The EncoderButton object that generated the event.
 */
void double_press_handler(EncoderButton &eb);

/**
 * Get the state of the double press flag.
 *
 * @return The state of the double press flag.
 */
bool get_double_press();

/**
 * Set the state of the double press flag.
 *
 * @param state: The state to set the double press flag to.
 */
void set_double_press(bool state);

/**
 * Get the state of the event status flag and reset it.
 *
 * @return The state of the event status flag.
 */
bool get_event_status();

/**
 * Set the state of the event status flag.
 *
 * @param state: The state to set the event status flag to.
 */
void set_event_status(bool state);

/**
 * Set the standby state of the display.
 *
 * @param state: The state to set the standby flag to.
 */
void set_dspl_standby(bool state);

bool get_standby_status();

bool get_saved_screen_state();

void set_saved_screen(bool state);

#endif

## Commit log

2023-10-21 Changed a lot
    changed menu structure, added bitmaps for displaying content, added controll structure for bitmaps, removed esp now - later replaced with artnet over wlan, removed pdc page due to irrelevancy
    [RLC_V3.ino, display.h, leds.cpp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]
2023-11-08 RLCV3-11 Artnet gets displayed correctly on led strip
    [RLC_V3.ino, display.h, leds.cpp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]
2023-11-08 RLCV3-11 Added rotary encoder navigation in main menu
2023-11-14 RLCV3-18 Dmx only wired
    for wireless use artnet
2023-12-12 RLCV3-31 Bugfix, Function implementation
    Fixed bug with last universe address
    packed function for outputting universe data
    [leds.cpp, leds.h]
2024-04-08 RLCV3-37 Added i2c color output func
2024-04-08 RLCV3-39 I2C slave code
    with modified library for neopixel
2024-04-08 RLCV3-38 Implementation of fan control
2024-04-09 RLCV3-38 Added fan control for HSV and RGB
2024-04-09 RLCV3-38 Added fan control for dmx, artnet and segment display
2024-04-10 RLCV3-40 Fixed button behavior on save screen
    [RLC_V3.ino, rotary_encoder.cpp, rotary_encoder.h]
2024-05-04 RLCV3-33 Added Acceleration to rotary encoder
2024-06-06 RLCV3-42 Adjusted main switch cases for new artnet page
2024-09-13 Fixed Bugs: Segment param; video dimming
    [fan_control.cpp, leds.cpp, leds.h]
2025-02-09 RLCV3-45 Changed Arduino use to PIO
    - split common.h file into c_hsv, c_rgb, menu_stucture modules and config.h and std_defines.h
    - removed artnet node page
2025-05-05 RLCV3-47 Added pcb gerber files
2025-05-05 RLCV3-44 updated fan control
2025-05-05 RLCV3-49 change config for devices
    - change defines for configurations of devices
    - added spotlight device
    - added info about configs
    - added checks for certain options
2025-05-05 RLCV3-49 Removed esp32s3 option in pio
2025-05-05 RLCV3-49 Added different handling of dmx for spotlight
    - a double usage of a pin with fan would crash dmx with spotlight device
2025-05-19 small commit \s
    - changed from platformio back to arduino due to reliability issues
    - no more overscrolling on main menu
    - changed segments page to settings menu
    - updated development notes
    [RLC_V3.ino, config.h]
2025-05-30 RLCV3-58 clamp rgb values between 0 and 255
2025-12-13 Add error handling for dmx
    [dmx.cpp, dmx.h]
2025-12-13 Update leds file
2025-12-15 Update reset function, add disable/enable
    [dmx.cpp, dmx.h]
2025-12-21 Remove old encoder handling; add new system
2025-12-21 Add software timer module
2025-12-21 Add software timer config
2025-12-27 Removed duplicate defines; minor bug fixes
    [leds.h]
2026-01-05 Update fan only values only at intervall
    - also making the ramp up faster than the ramp down
2026-02-27 Added 3d models
    [cable_channel.3mf, cable_channel.FCStd, cable_clip.3mf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]
2026-02-27 Add script to convert bom csv to latex table notation
2026-03-04 Add bom and pictures
    [BOM.csv]
